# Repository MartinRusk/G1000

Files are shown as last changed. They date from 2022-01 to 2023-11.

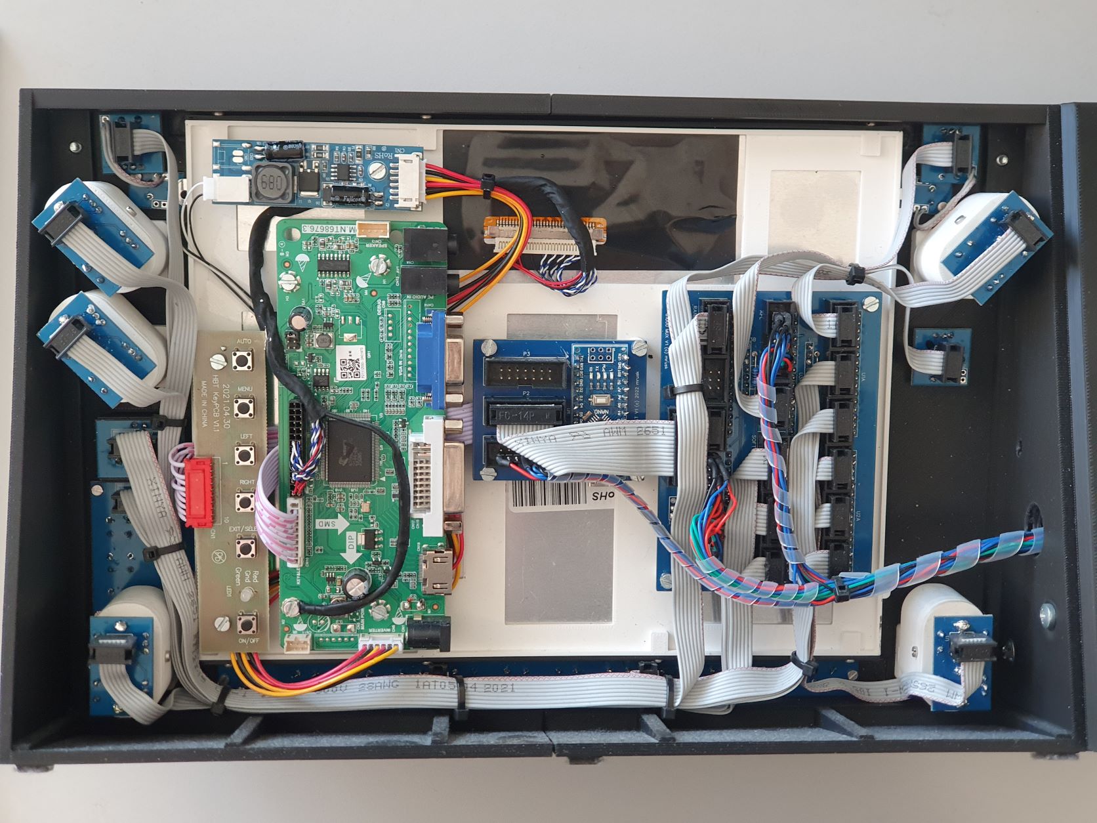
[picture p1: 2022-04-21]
design/G1000 Rear side.jpg

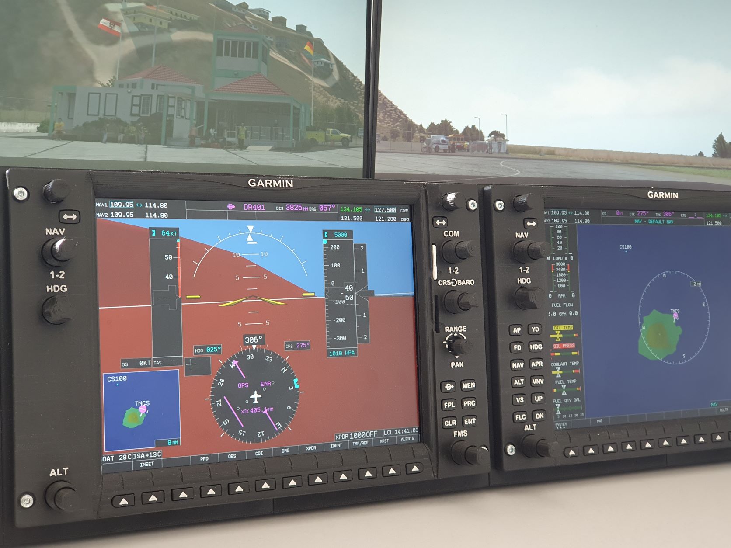
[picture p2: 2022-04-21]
design/G1000.jpg

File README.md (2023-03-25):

# G1000 

This repository hosts the firmware and design files for the mrusk G1000 device. 

The master branch now uses the XPLDirect driver for X-Plane by Curiosity Workshop. Software is (c) by mrusk and Curiosity Workshop. 
For the previously supported RealSimGear driver solution (also for MSFS2020) please look into the RealSimGear branch. Software provided here is licensed under GPL V3.0 License.

Please visit the Curiosity Workshop Discord https://discord.gg/gzXetjEST4 and the FlightSimMaker Discord https://discord.gg/YVbK6dmkeV.

3D Design also available at Printables: https://www.printables.com/de/model/199536-flight-simulator-g1000-nxi

PCBs to build the solution are currently out of stock. Order details are given in the building instructions. In case of trouble you may contact me via g1000nxi@outlook.de

3D design files are (c) by DKF and mrusk, licensed under a
[Creative Commons Attribution-NonCommercial-ShareAlike 4.0 International License][cc-by-nc-sa].

[][cc-by-nc-sa]

[cc-by-nc-sa]: http://creativecommons.org/licenses/by-nc-sa/4.0/
[cc-by-nc-sa-image]: https://licensebuttons.net/l/by-nc-sa/4.0/88x31.png
[cc-by-nc-sa-shield]: https://img.shields.io/badge/License-CC%20BY--NC--SA%204.0-lightgrey.svg

PCB design files are (c) by mrusk, licensed under a
[Creative Commons Attribution-NonCommercial-NoDerivatives 4.0 International License][cc-by-nc-nd].

[][cc-by-nc-nd]

[cc-by-nc-nd]: http://creativecommons.org/licenses/by-nc-nd/4.0/
[cc-by-nc-nd-image]: https://licensebuttons.net/l/by-nc-nd/4.0/88x31.png
[cc-by-nc-nd-shield]: https://img.shields.io/badge/License-CC%20BY--NC--ND%204.0-lightgrey.svg

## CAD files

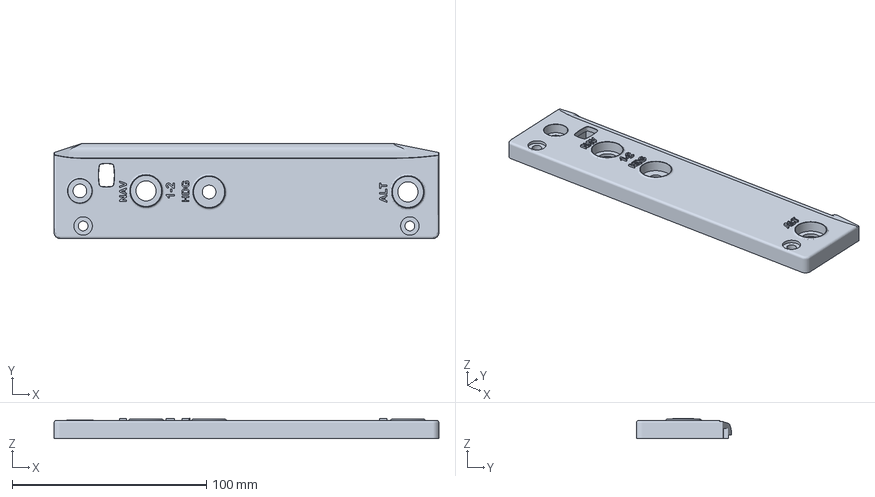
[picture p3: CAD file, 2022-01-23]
design/Bezel/Bezel Left PFD.3mf
198.0 x 49.0 x 10.4 mm

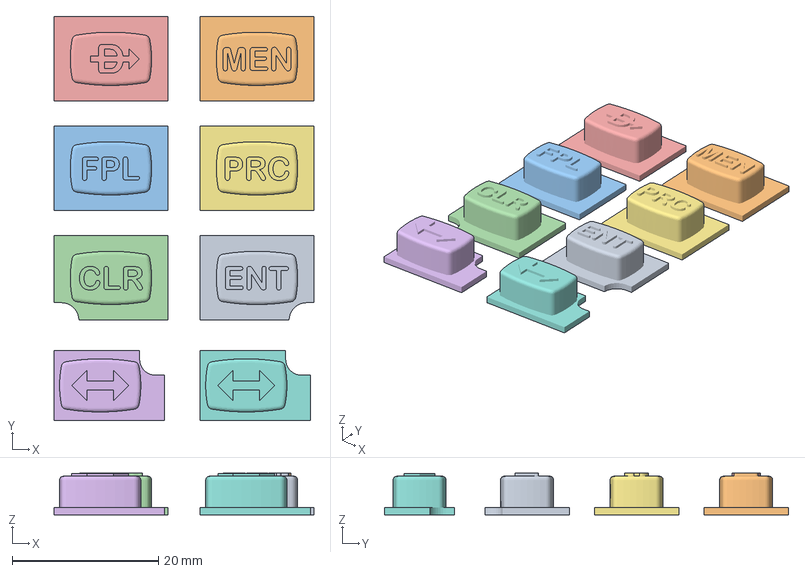
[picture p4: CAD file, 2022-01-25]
design/Buttons/Buttons PFD.3mf
35.6 x 55.3 x 5.69 mm
Buttons erhaben 0.4mm_9
Buttons erhaben 0.4mm_10
Buttons erhaben 0.4mm_12
Buttons erhaben 0.4mm_13
Buttons erhaben 0.4mm_14
Buttons erhaben 0.4mm_17
Buttons erhaben 0.4mm_19
Buttons erhaben 0.4mm_22

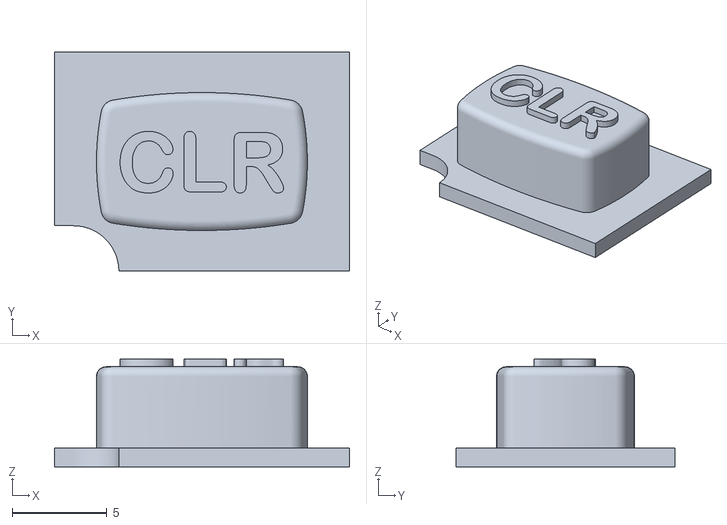
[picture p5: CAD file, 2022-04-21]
design/Buttons/STL/CLR.stl
15.6 x 11.6 x 5.69

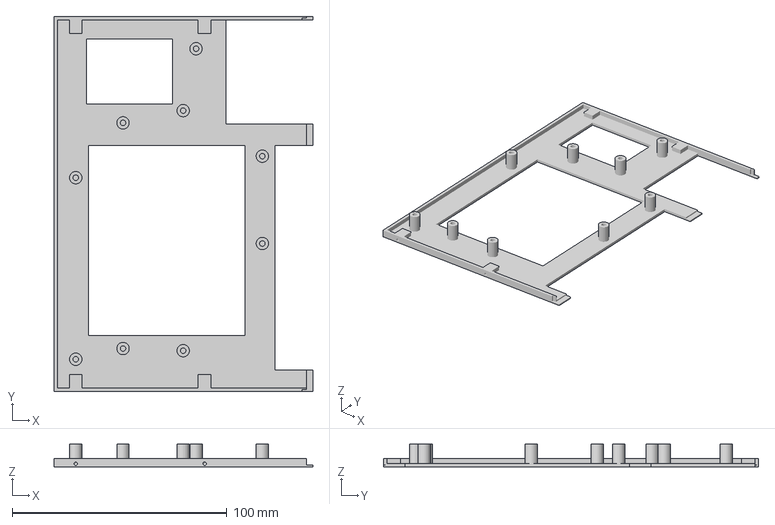
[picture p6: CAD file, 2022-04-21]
design/Display/Display_Bracket_Left.3mf
120.3 x 174.5 x 10.6 mm

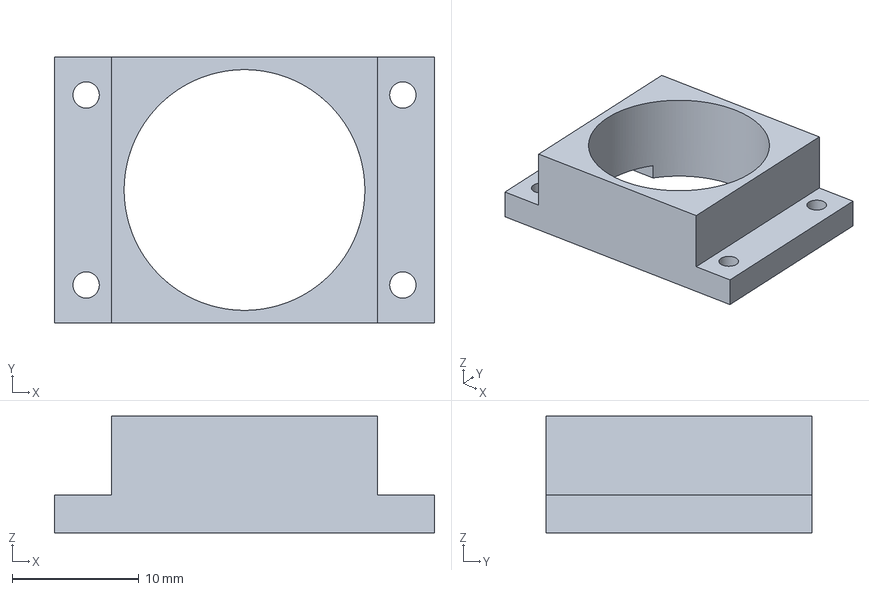
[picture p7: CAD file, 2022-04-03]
design/Encoders/Range Pan Frame.3mf
30.0 x 21.0 x 9.20 mm

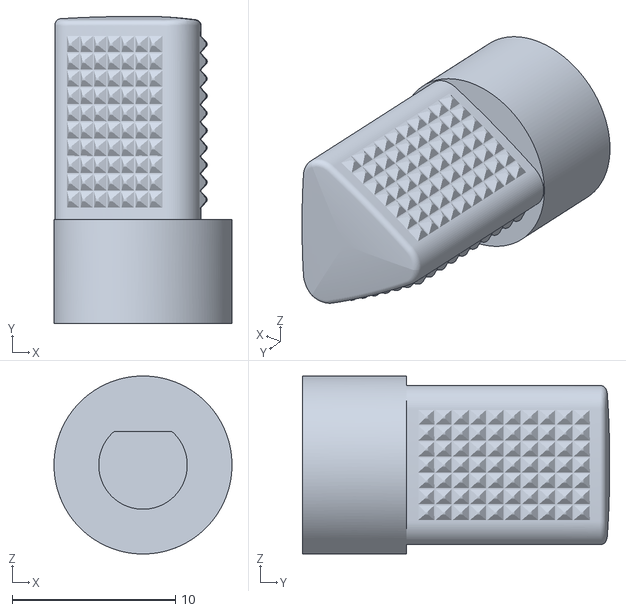
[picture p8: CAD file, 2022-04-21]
design/Encoders/STL/Encoder Knob CRS Inner.stl
10.9 x 18.8 x 10.9

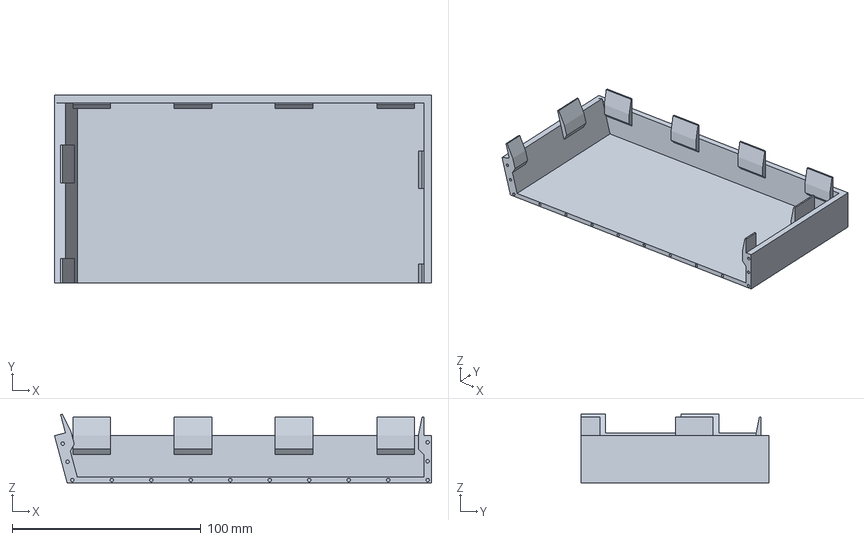
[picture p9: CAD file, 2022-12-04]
design/Housing/Back cover right MFD.3mf
200.0 x 99.5 x 36.5 mm

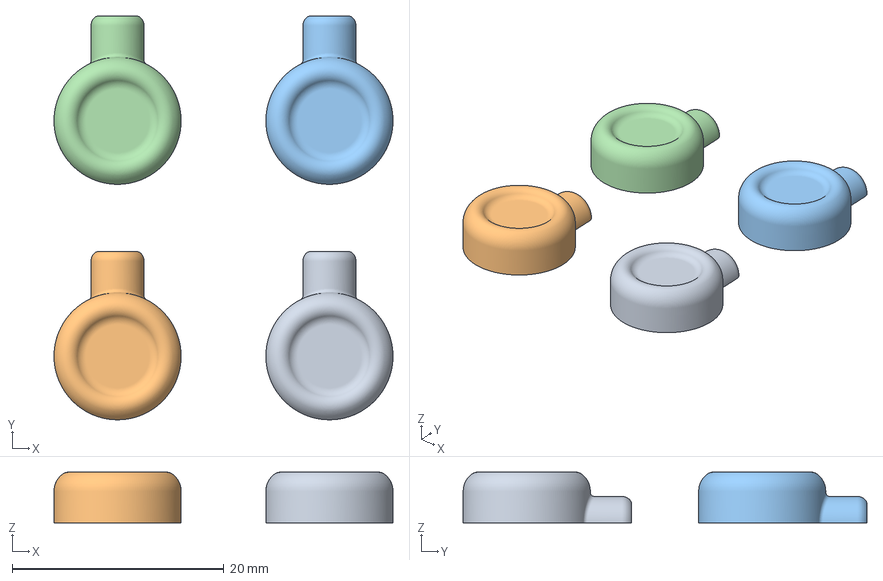
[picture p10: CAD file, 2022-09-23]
design/Panel/Fuel handle.3mf
32.0 x 38.1 x 4.80 mm
Fuel handle right.stl
Fuel handle left.stl

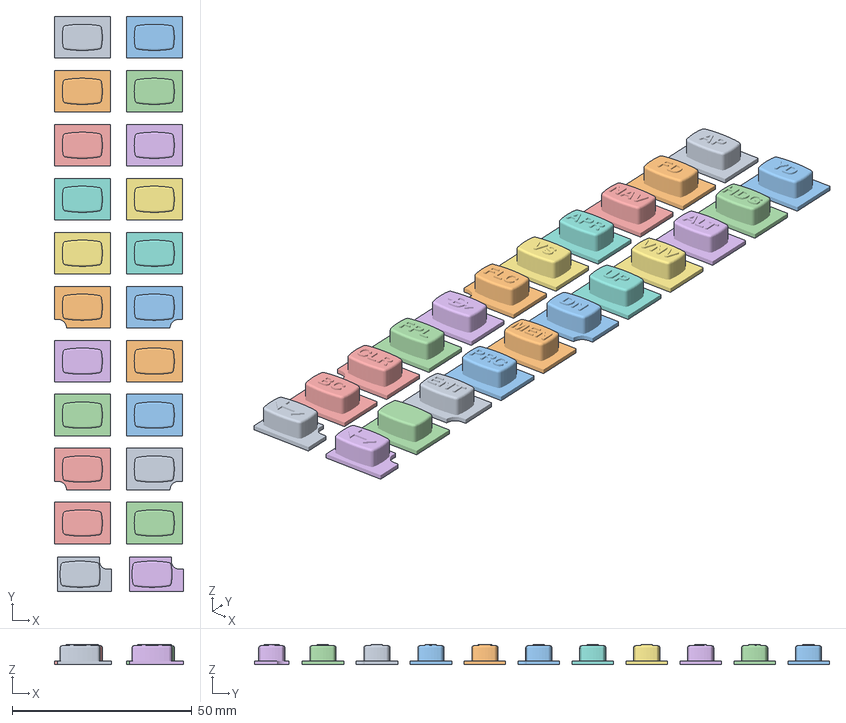
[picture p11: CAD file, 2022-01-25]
design/Buttons/Buttons MFD.3mf
36.0 x 159.8 x 5.69 mm
Buttons erhaben 0.4mm_1
Buttons erhaben 0.4mm_2
Buttons erhaben 0.4mm_3
Buttons erhaben 0.4mm_4
Buttons erhaben 0.4mm_5
Buttons erhaben 0.4mm_6
Buttons erhaben 0.4mm_7
Buttons erhaben 0.4mm_8
Buttons erhaben 0.4mm_9
Buttons erhaben 0.4mm_10
Buttons erhaben 0.4mm_11
Buttons erhaben 0.4mm_12
Buttons erhaben 0.4mm_13
Buttons erhaben 0.4mm_14
Buttons erhaben 0.4mm_15
Buttons erhaben 0.4mm_16
Buttons erhaben 0.4mm_17
Buttons erhaben 0.4mm_18
Buttons erhaben 0.4mm_19
Buttons erhaben 0.4mm_20
Buttons erhaben 0.4mm_21
Buttons erhaben 0.4mm_22

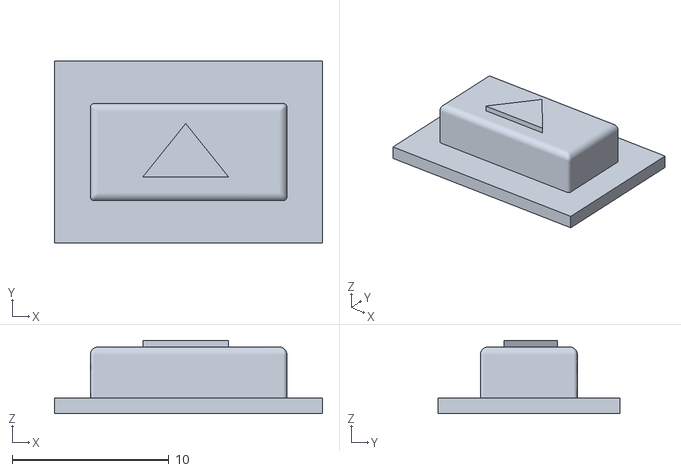
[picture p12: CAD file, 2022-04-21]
design/Buttons/STL/KEY 8.stl
17.1 x 11.6 x 4.67

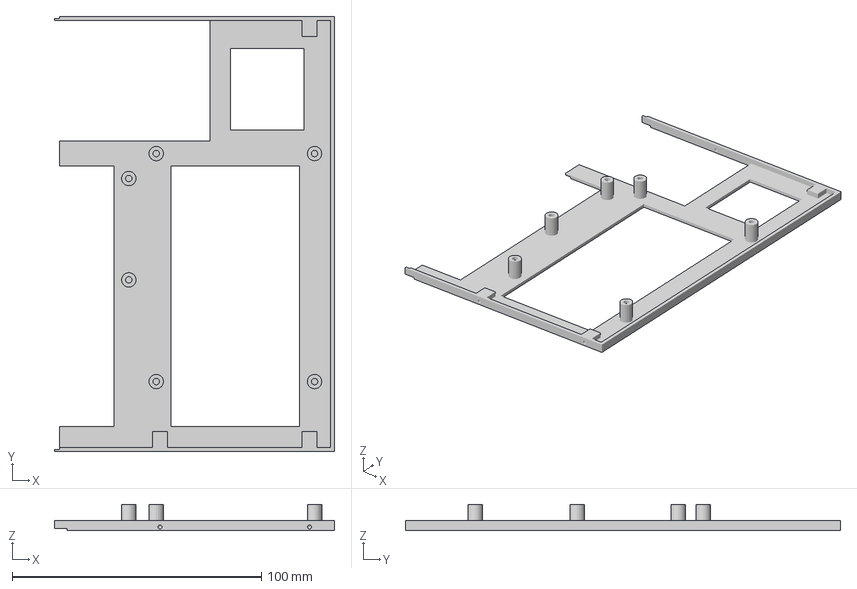
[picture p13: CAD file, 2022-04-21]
design/Display/Display_Bracket_Right.3mf
112.3 x 174.5 x 10.6 mm

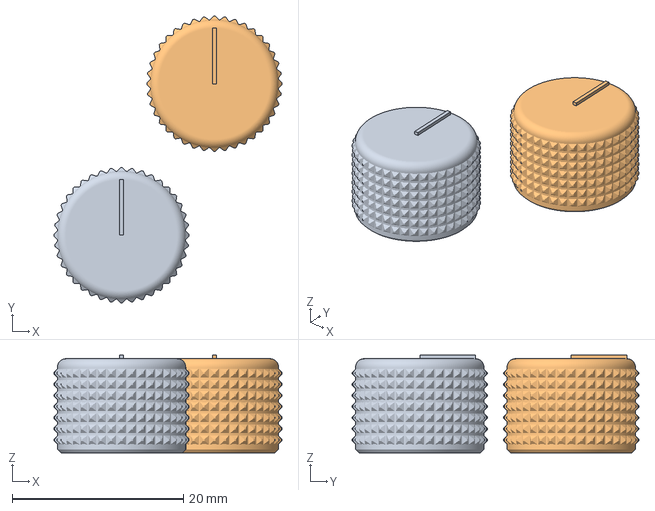
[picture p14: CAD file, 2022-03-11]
design/Encoders/Poti Knob.3mf
26.7 x 33.5 x 11.4 mm

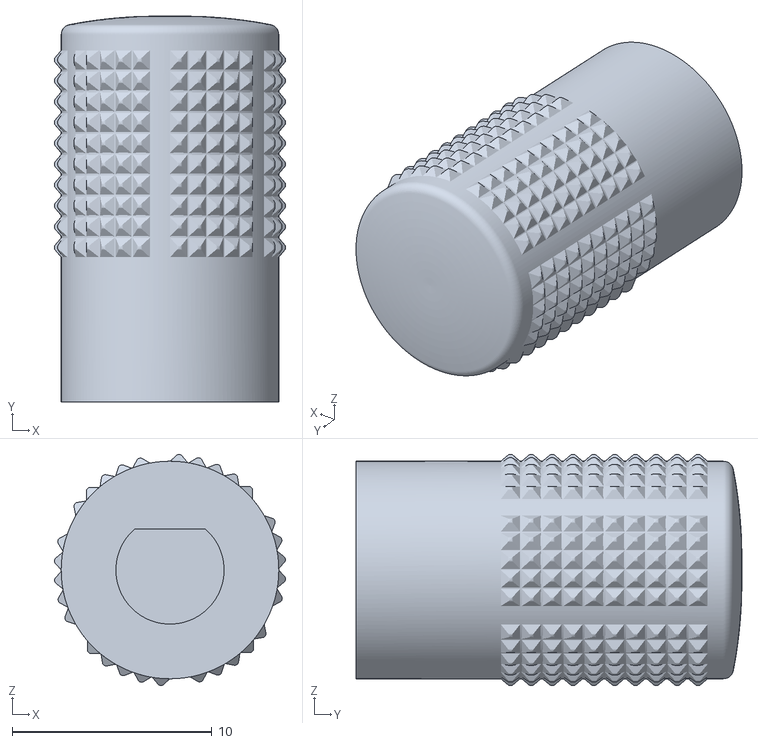
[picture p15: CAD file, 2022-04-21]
design/Encoders/STL/Encoder Knob Dual Inner.stl
11.6 x 19.3 x 11.6

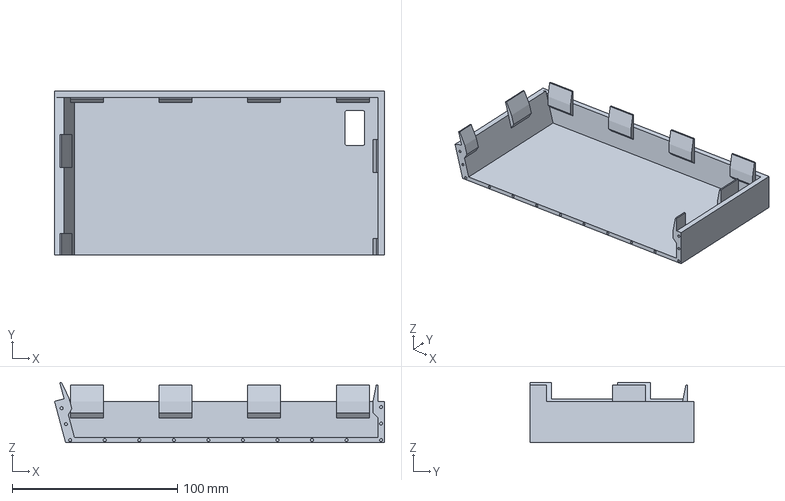
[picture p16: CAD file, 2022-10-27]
design/Housing/Back cover right PFD.3mf
200.0 x 99.5 x 36.5 mm

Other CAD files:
design/Bezel/Bezel Left MFD.3mf
design/Panel/Gear handle.3mf
design/Bezel/Bezel Top.3mf
design/Buttons/Buttons KEY.3mf
design/Bezel/Bezel Bottom.3mf
design/Bezel/Bezel Right.3mf
design/Bezel/Bezel SD Card.3mf
design/Bezel/STL/Bezel Bottom.stl
design/Bezel/STL/Bezel Left MFD.stl
design/Bezel/STL/Bezel Left PFD.stl
design/Bezel/STL/Bezel Right.stl
design/Bezel/STL/Bezel SD Card.stl
design/Bezel/STL/Bezel Top.stl
design/Buttons/STL/ALT.stl
design/Buttons/STL/AP.stl
design/Buttons/STL/APR.stl
design/Buttons/STL/BC.stl
design/Buttons/STL/Blank.stl
design/Buttons/STL/DN.stl
design/Buttons/STL/Dto.stl
design/Buttons/STL/ENT.stl
design/Buttons/STL/FD.stl
design/Buttons/STL/FFL.stl
design/Buttons/STL/FFR.stl
design/Buttons/STL/FLC.stl
design/Buttons/STL/FPL.stl
design/Buttons/STL/HDG.stl
design/Buttons/STL/KEY 1.stl
design/Buttons/STL/KEY 10.stl
design/Buttons/STL/KEY 11.stl
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

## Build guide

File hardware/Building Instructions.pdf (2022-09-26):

# Building the mrusk G1000 panel

## Part list for PFD+MFD

Part | Type | Amount | Source
PCB set | | 1 | mrusk
Encoder | EC11 | 26 | https://www.ebay.de/itm/182373237976
ALPS | RKJXT1F42001 | 2 | https://www.ebay.de/itm/164837499516
Switch | 6x6x5mm | 52 | https://www.reichelt.de/kurzhubtaster-6x6mm-hoehe-5-0mm-12v-vertikal-taster-9302-p44579.html (https://www.reichelt.de/kurzhubtaster-6x6mm-hoehe-5-0mm-12v-vertikal-taster-9302-p44579.html)
IDC Header | 6 pin | 18 | https://www.ebay.de/itm/362257230215
IDC Plug | 6 pin | 34 | https://www.ebay.de/itm/183463370948
IDC Header | 8 pin | 8 | https://www.ebay.de/itm/312078634350
IDC Plug | 8 pin | 16 | https://www.ebay.de/itm/312252897256
IDC Header | 14 pin | 8 | https://www.ebay.de/itm/312078591715
IDC Plug | 14 pin | 9 | https://www.ebay.de/itm/312252873182
Pin Header | Single row | Ca. 300 pins | https://www.reichelt.de/40pol-stiftleiste-gerade-rm-2-54-sl-1x40g-2-54-p19506.html (https://www.reichelt.de/40pol-stiftleiste-gerade-rm-2-54-sl-1x40g-2-54-p19506.html)
Pin Header | Double row | Ca. 70x2 pins | https://www.reichelt.de/2x40pol-stiftleiste-gerade-rm-2-54-sl-2x40g-2-54-p19498.html (https://www.reichelt.de/2x40pol-stiftleiste-gerade-rm-2-54-sl-2x40g-2-54-p19498.html)
Resistor 1/4W | 10 kΩ | 10
74HC4067 | Module | 10 | https://www.ebay.de/itm/265408479238
Screw | M3x5mm | 30
Screw | M2x5mm | 20
Ribbon cable | 14pin (Split for 6 and 8) | | https://www.reichelt.de/flachbandkabel-awg28-14-pol-grau-10m-ring-awg-28-14g-10m-p47653.html (https://www.reichelt.de/flachbandkabel-awg28-14-pol-grau-10m-ring-awg-28-14g-10m-p47653.html)
Display | VS104T-003 | 2 | https://de.aliexpress.com/item/4000156062102.html
Arduino MEGA 2560 | | 1

For OPTIONAL Backlight
LED white 1206 | white | 24 | https://www.reichelt.de/led-smd-3216-1206-warmweiss-900-mcd-120--led-ll-1206-ww-p156359.html (https://www.reichelt.de/led-smd-3216-1206-warmweiss-900-mcd-120--led-ll-1206-ww-p156359.html)
Resistor 1206 | 100 Ω | 24 | https://www.reichelt.de/smd-widerstand-1206-100-ohm-250-mw-1--vis-crcw12061002-p238101.html (https://www.reichelt.de/smd-widerstand-1206-100-ohm-250-mw-1--vis-crcw12061002-p238101.html)

## PCB Set

Shortcut | Usage | Amount | Panel Size | Panels needed
APL | Autopilot (MFD only) | 1 | 2 x 1 | 1
FMS | Flight Management System | 2 | 2 x 1 | 1
Enc | Single Encoder (Volume, Heading) | 6 | 4 x 4 | 1
DualEnc | Dual Encoder | 10 | 2 x 4 | 2
FF | Frequency Flip Flop Key | 4 | 4 x 5 | 1
Range | Range/Pan knob | 2 | 2 x 3 | 1
Softkey | Softkey bar | 2 | 1 x 1 | 2
MUX | Multiplexer carrier | 2 | 1 x 1 | 2
HAT | Connector to Arduino MEGA 2560 | 1 | 1 x 2 | 1
MICRO_HAT and NANO_HAT are for Arduino Pro Micro and Arduino Nano respectively, but are not really recommended due to performance and driver issues.

Order using the Gerber files at https://jlcpcb.com. Set the parameters according to the screenshot below (example is for APL board). Dimensions are determined automatically from the Gerber file. Select “Panel by Customer” and set Columns / Rows according to the table above. PCB Color blue if you like and make sure the “Stencil” at the bottom of the page is not selected. Minimum Quantity is 5 panels each.

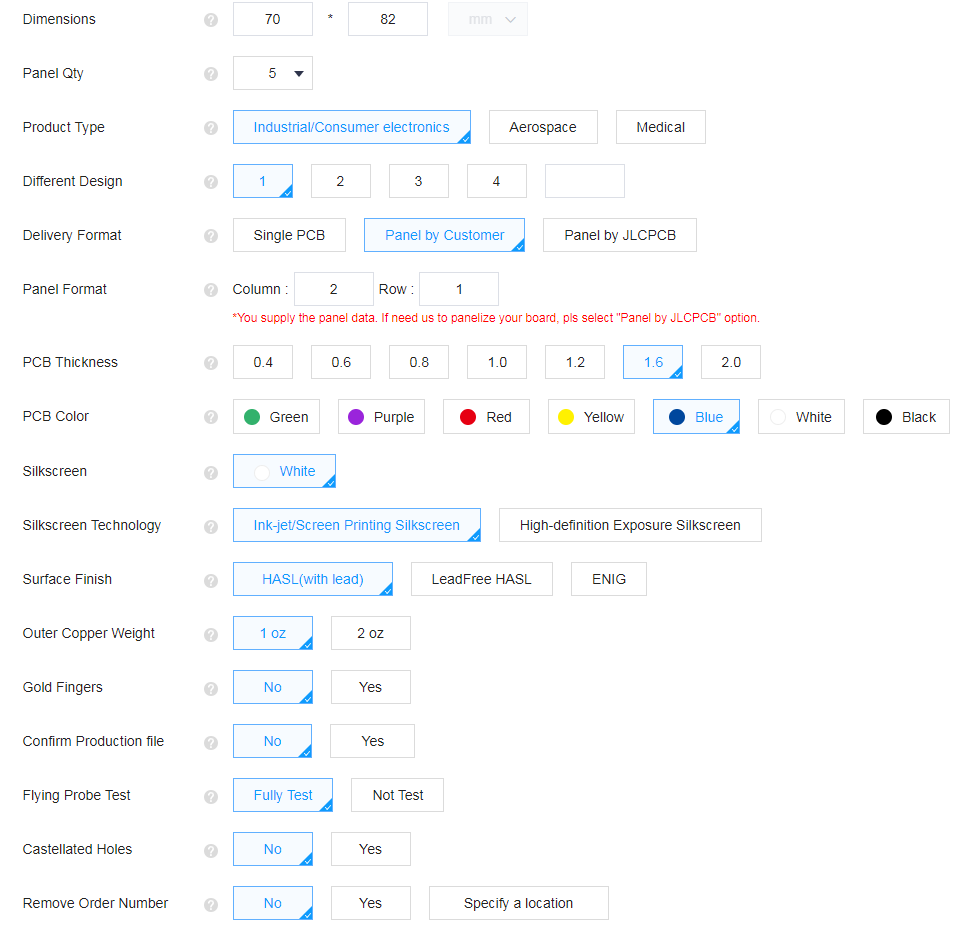
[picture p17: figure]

## Special mounting instructions

MUX Board
- Mount Multiplexers on BOTTOM side, parts facing UPWARDS (see picture). Spacing by headers with additional separator from further header pins.
- MUX 6 is optional and can be left free.
- Solder IDC sockets first and MUX boards last when all pins were tested.
ENC and DENC Boards
- Use 2x3 header pin, not IDC connector. Remove plastic pin underneath the encoder. Space is needed for header pins.
- Each ENC board has one free input (connect to FF boards).
- Connector on DENC board is facing to the outside
RANGE Board
- Solder pin header from bottom so that the pins do not appear on top side. FF Board
- Wire J1 directly to ENC board next to it.
HAT board
- Solder header connection to MEGA2560 on bottom side.
- One 14 pin cable per unit, two slots are spare.

MUX Inputs
DENC1 | NAV
DENC2 | COM
DENC3 | CRS/BARO
DENC4 | ALT
DENC5 | FMS
ENC1 | NAV VOL
ENC2 | COM VOL
ENC3 | HDG
DENC6 | spare

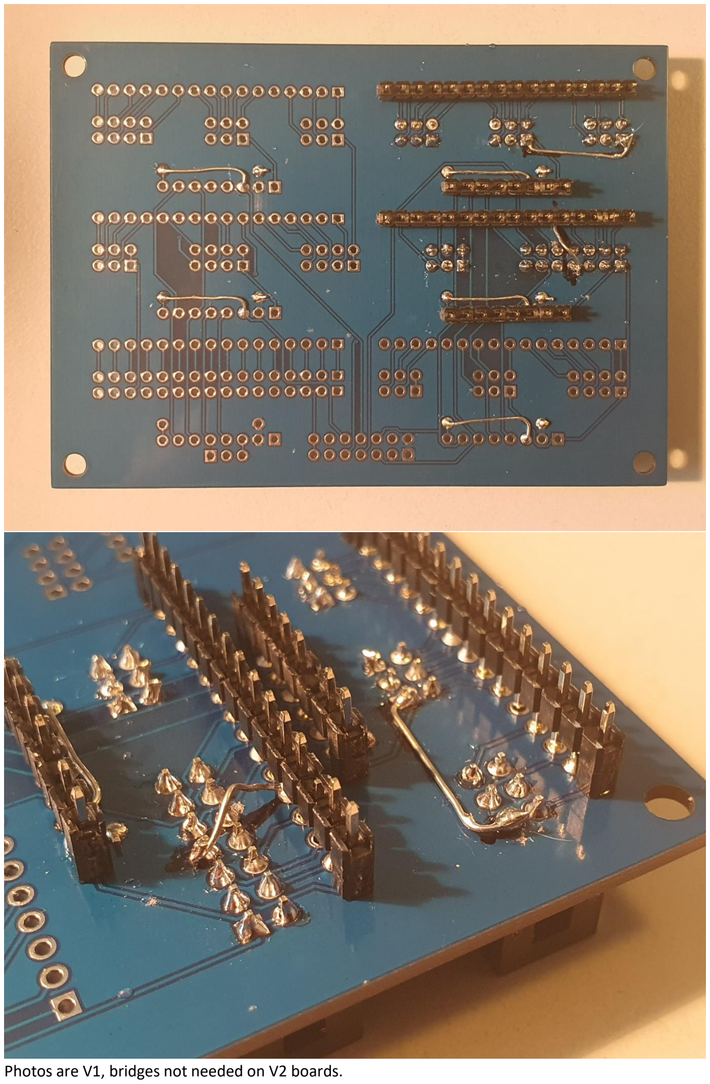
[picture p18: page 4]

Photos are V1, bridges not needed on V2 boards.

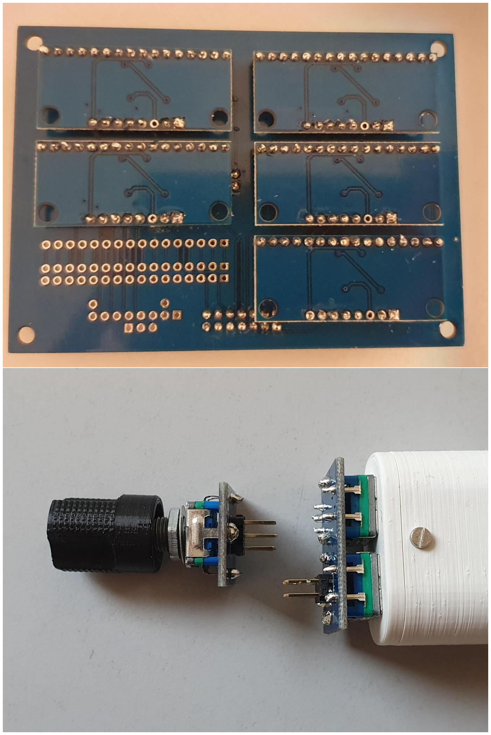
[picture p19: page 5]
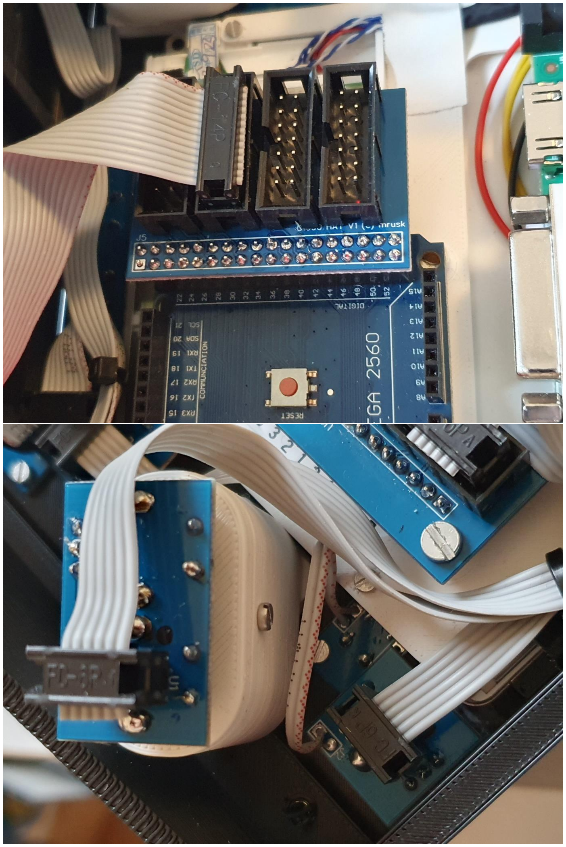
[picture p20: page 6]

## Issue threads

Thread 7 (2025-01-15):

Editing of PCBs

Wibbbs, 2025-01-15:
Hello, I would like to use some of the pieces you have in the the repo here but I would like to make a couple small edits to some of the PCBs you have to accept some different buttons that I have. Any change you could post the easyeda files so they could be edited.

Wibbbs, 2025-01-15:
Spoke with you on discord. Thanks for the helpw

Wibbbs, 2025-01-15:
Spoke with you on discord, thanks for the help.

Closed 2025-01-15.

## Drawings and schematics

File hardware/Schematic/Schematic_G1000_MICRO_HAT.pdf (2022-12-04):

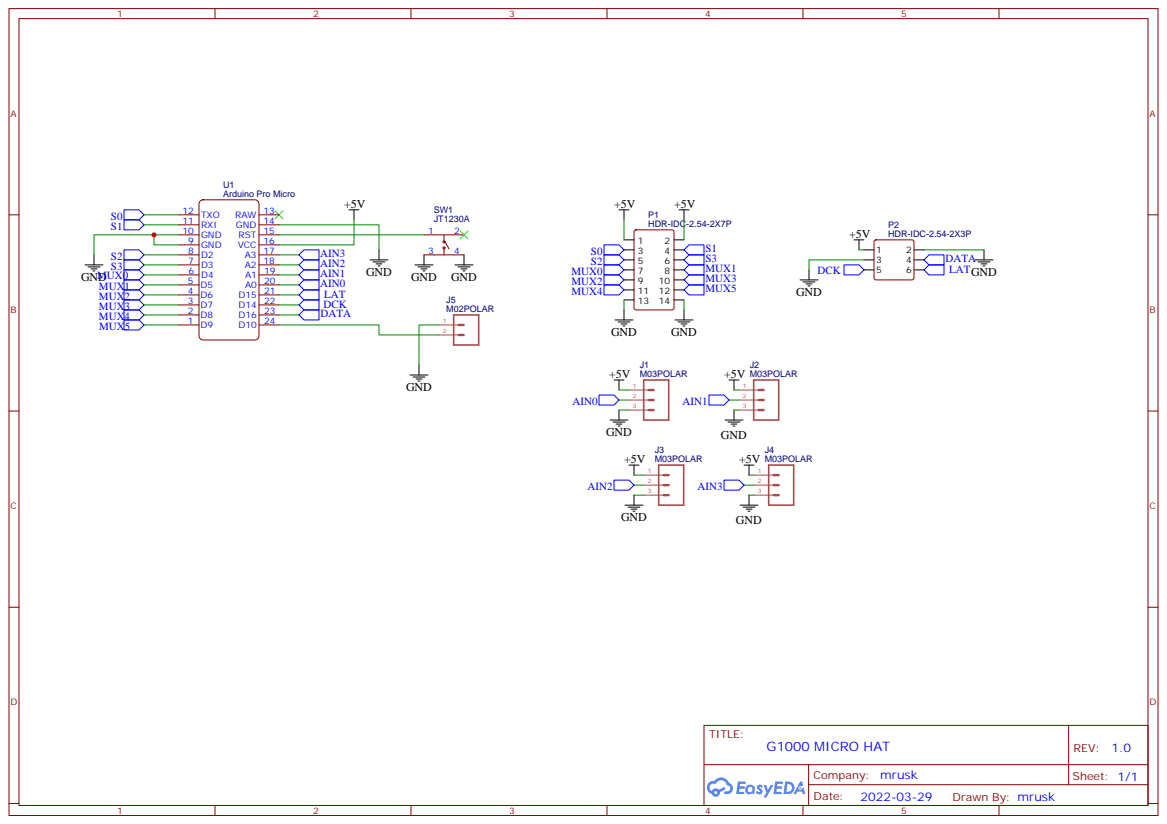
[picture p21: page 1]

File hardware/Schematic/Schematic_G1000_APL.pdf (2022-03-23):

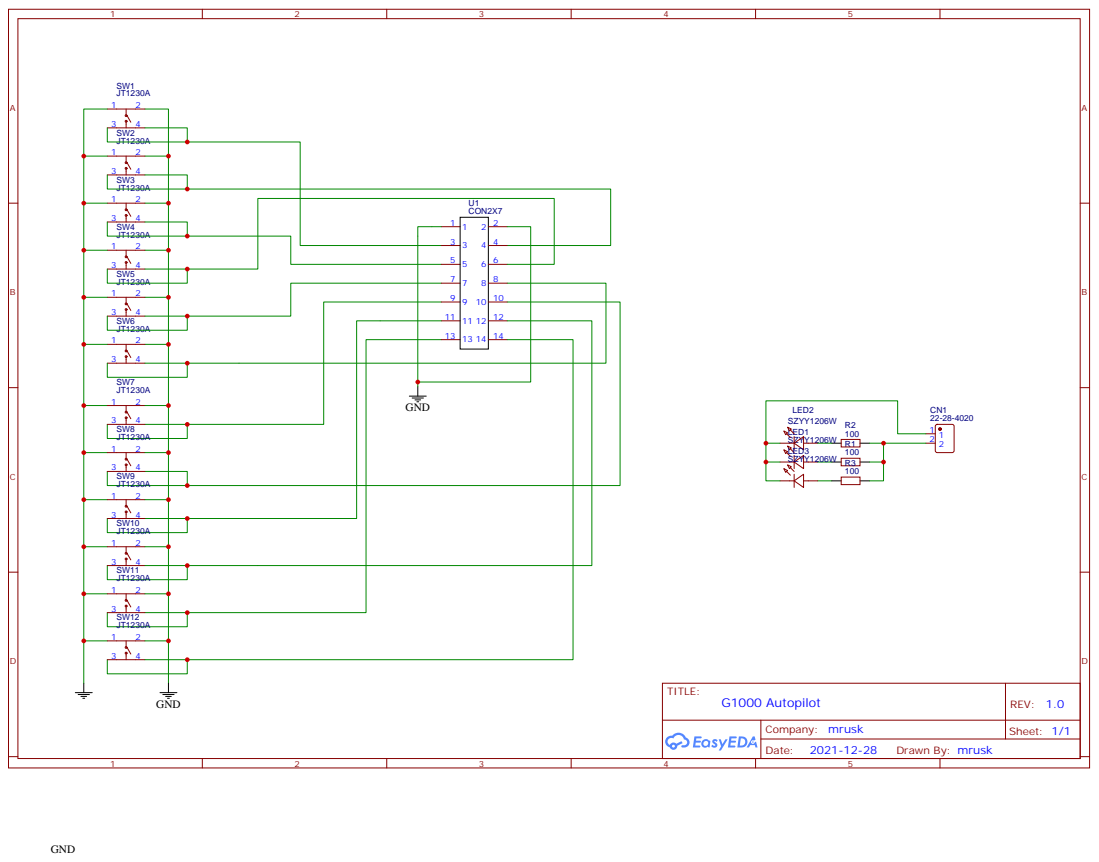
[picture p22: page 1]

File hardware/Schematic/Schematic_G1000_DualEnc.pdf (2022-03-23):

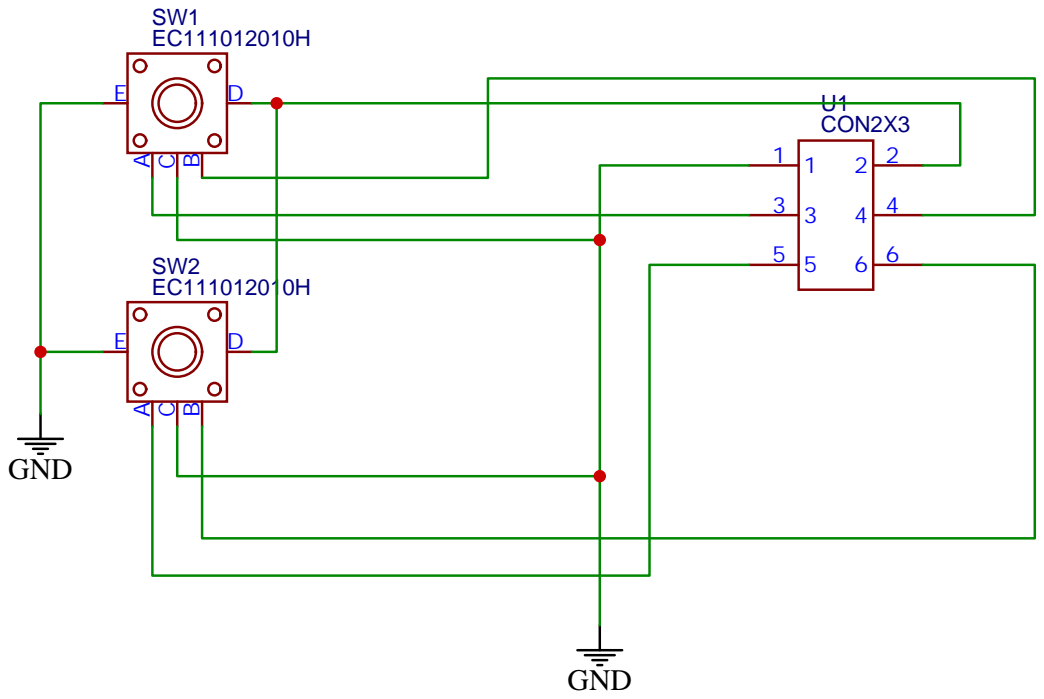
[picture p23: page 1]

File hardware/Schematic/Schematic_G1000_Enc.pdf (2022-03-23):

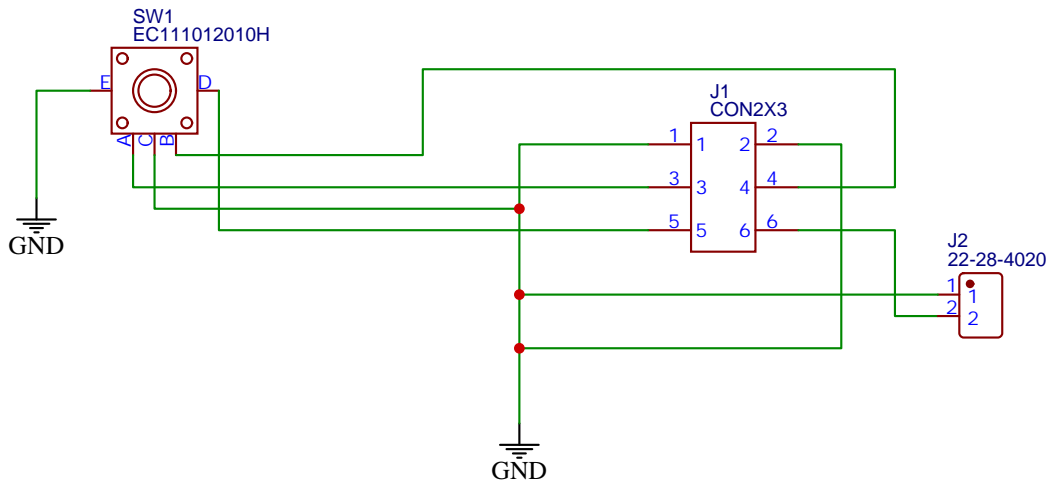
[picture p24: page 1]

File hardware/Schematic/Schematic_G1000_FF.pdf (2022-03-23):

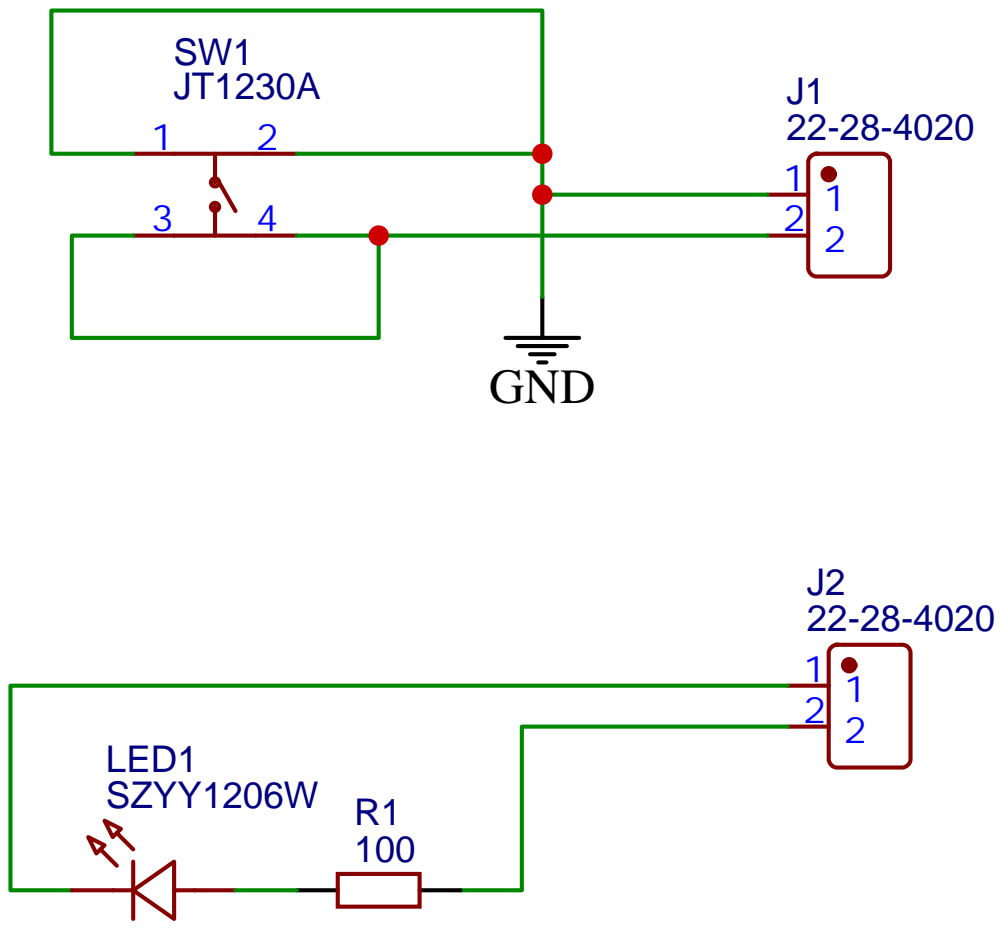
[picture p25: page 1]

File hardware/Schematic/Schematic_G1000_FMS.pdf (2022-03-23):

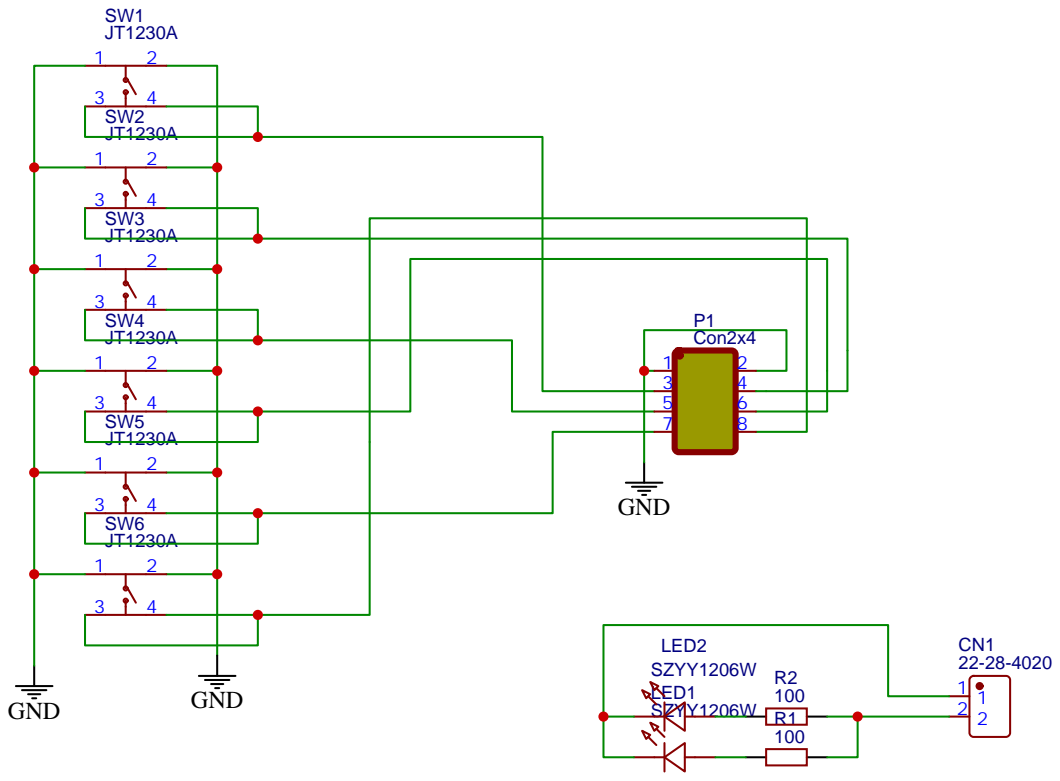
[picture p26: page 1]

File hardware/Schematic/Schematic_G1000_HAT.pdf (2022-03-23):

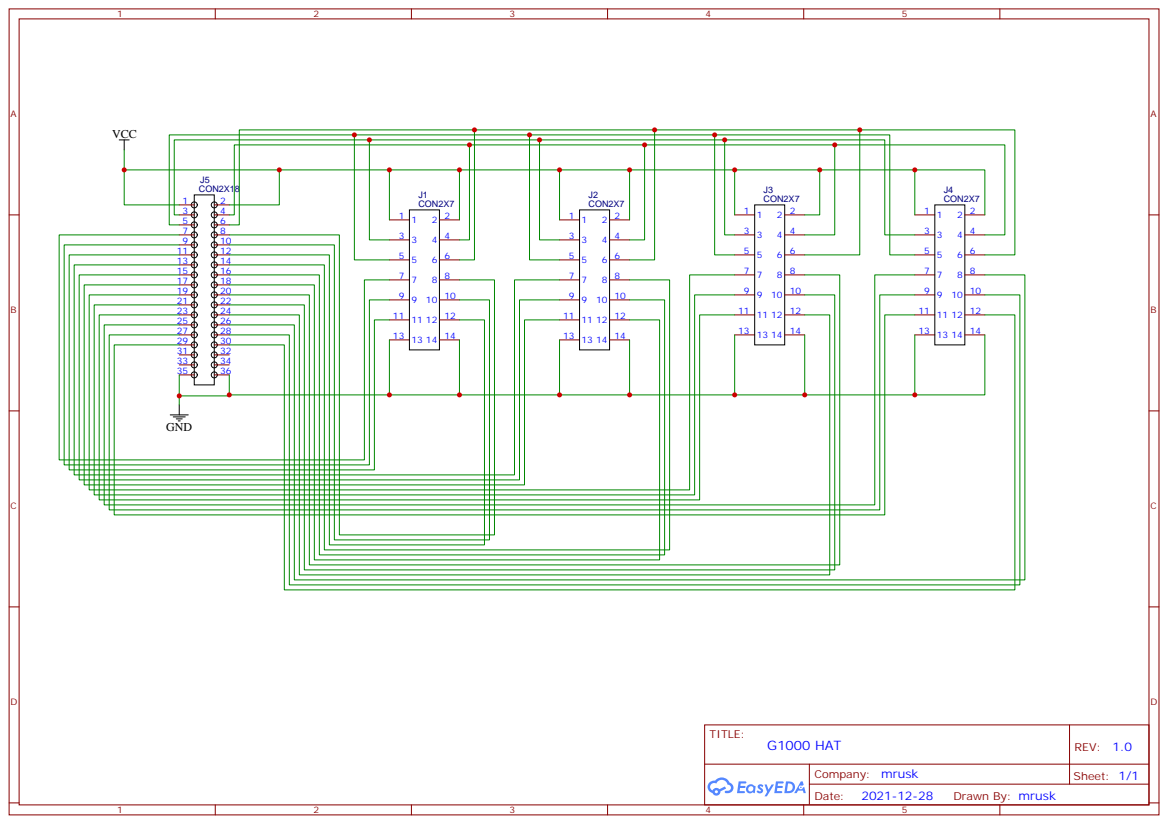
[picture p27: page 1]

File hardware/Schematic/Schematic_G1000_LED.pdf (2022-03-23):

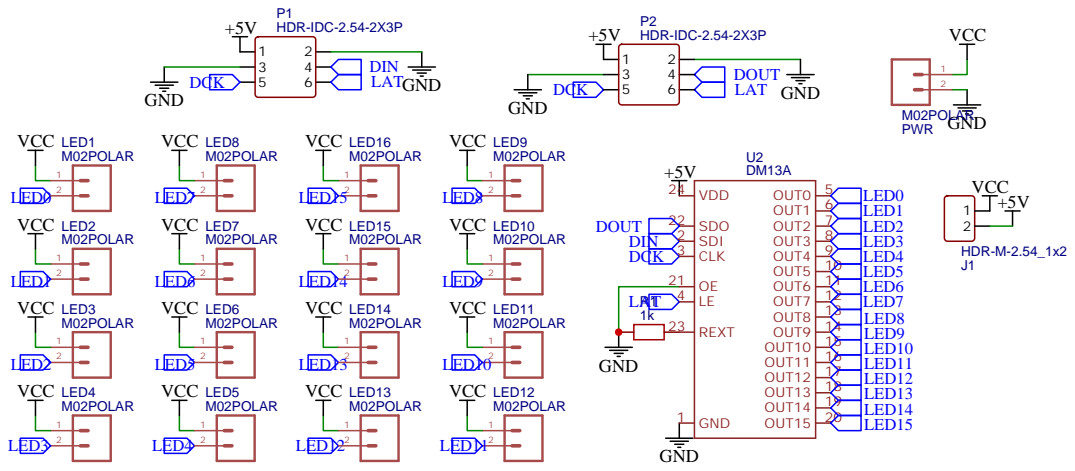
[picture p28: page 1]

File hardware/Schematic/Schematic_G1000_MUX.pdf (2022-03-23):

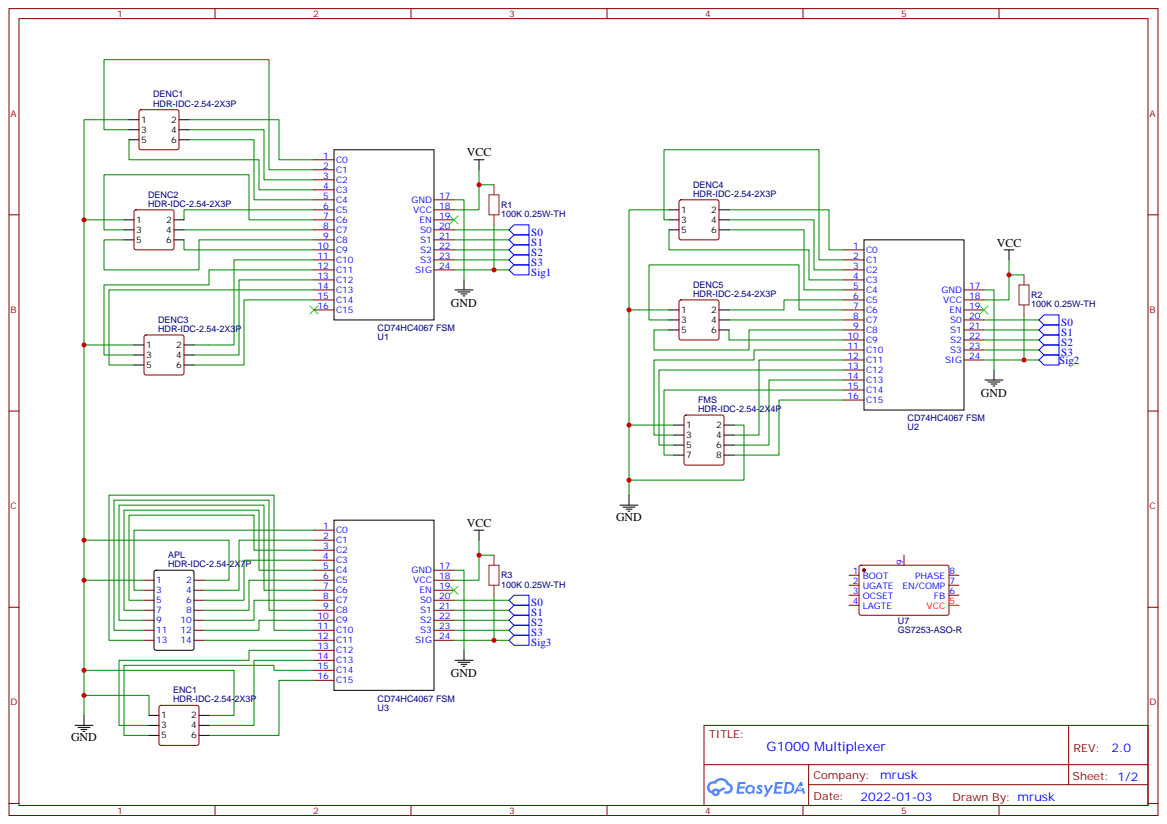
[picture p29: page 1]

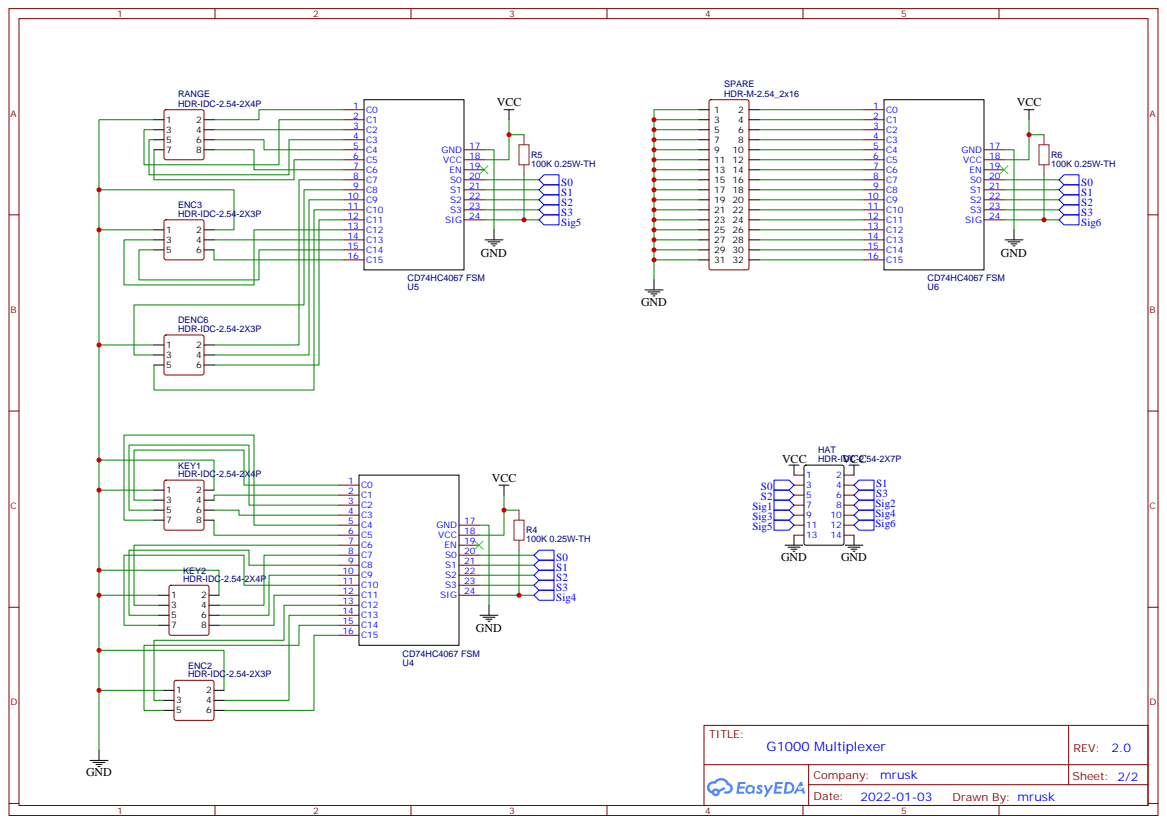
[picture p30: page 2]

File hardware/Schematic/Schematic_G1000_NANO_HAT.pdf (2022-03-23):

A | A

1

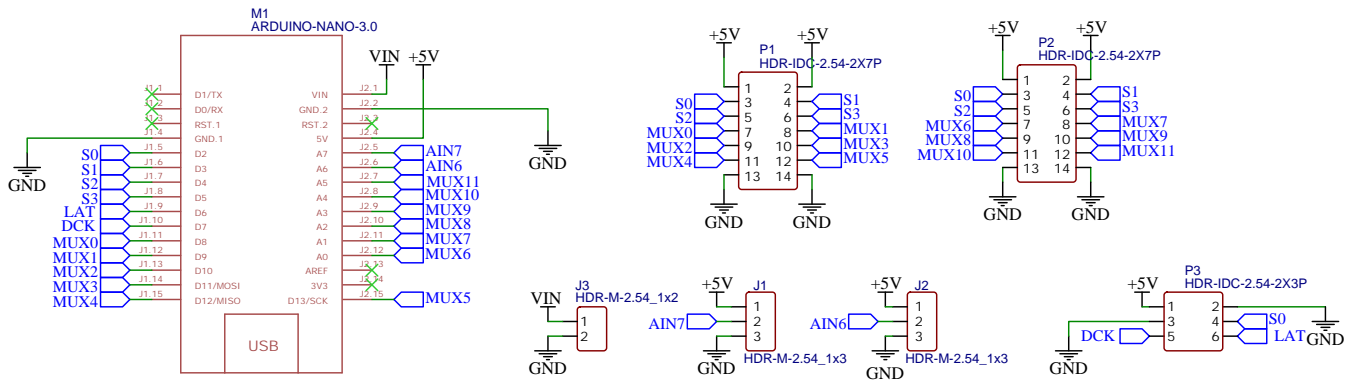
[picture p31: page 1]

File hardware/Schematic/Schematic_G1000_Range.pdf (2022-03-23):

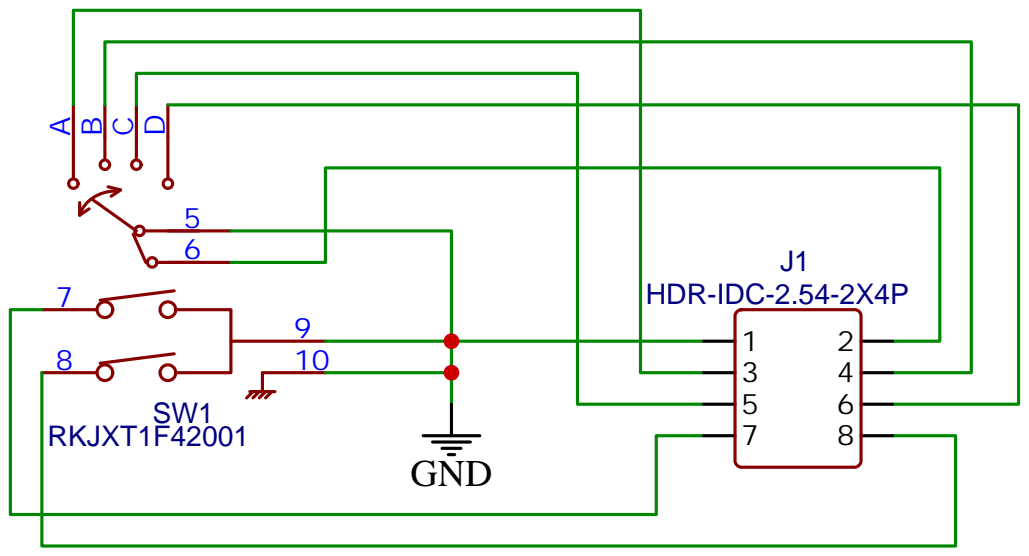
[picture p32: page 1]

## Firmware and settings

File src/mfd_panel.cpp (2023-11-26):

#include <Arduino.h>
#include <XPLDevices.h>

#if G1000_MFD

// MUX 0
Encoder encNavInner(0, 1, 2, 0, enc4Pulse);
Encoder encNavOuter(0, 4, 3, NOT_USED, enc4Pulse);
Encoder encComInner(0, 6, 7, 5, enc4Pulse);
Encoder encComOuter(0, 9, 8, NOT_USED, enc4Pulse);
Encoder encCourse(0, 11, 12, 10, enc4Pulse);
Encoder encBaro(0, 14, 13, NOT_USED, enc4Pulse);
// MUX 1
Encoder encAltInner(1, 1, 2, 0, enc4Pulse);
Encoder encAltOuter(1, 4, 3, NOT_USED, enc4Pulse);
Encoder encFMSInner(1, 6, 7, 5, enc4Pulse);
Encoder encFMSOuter(1, 9, 8, NOT_USED, enc4Pulse);
Button btnDirect(1, 10);
Button btnFPL(1, 11);
Button btnCLR(1, 12);
Button btnMENU(1, 13);
Button btnPROC(1, 14);
Button btnENT(1, 15);
// MUX 2
Button btnAP(2, 0);
Button btnFD(2, 1);
Button btnNAV(2, 2);
Button btnALT(2, 3);
Button btnVS(2, 4);
Button btnFLC(2, 5);
Button btnYD(2, 6);
Button btnHDG(2, 7);
Button btnAPR(2, 8);
Button btnVNAV(2, 9);
Button btnUP(2, 10);
Button btnDN(2, 11);
Encoder encNavVol(2, 12, 13, 14, enc4Pulse);
Button btnNavFF(2, 15);
// MUX3
Button btnSoft1(3, 0);
Button btnSoft2(3, 1);
Button btnSoft3(3, 2);
Button btnSoft4(3, 3);
Button btnSoft5(3, 4);
Button btnSoft6(3, 5);
Button btnSoft7(3, 6);
Button btnSoft8(3, 7);
Button btnSoft9(3, 8);
Button btnSoft10(3, 9);
Button btnSoft11(3, 10);
Button btnSoft12(3, 11);
Encoder encComVol(3, 12, 13, 14, enc4Pulse);
Button btnComFF(3, 15);
// MUX4 Pan/Zoom
Encoder encRange(4, 6, 5, 0, enc2Pulse);
Button btnPanPush(4, 0);
RepeatButton btnPanUp(4, 1, 250);
RepeatButton btnPanLeft(4, 2, 250);
RepeatButton btnPanDown(4, 3, 250);
RepeatButton btnPanRight(4, 4, 250);
Encoder encHeading(4, 12, 13, 14, enc4Pulse);

// MFD specific
Encoder encRudderTrim(4, 8, 9, 10, enc4Pulse);
Switch swLightLanding(5, 0);
Switch swLightTaxi(5, 1);
Switch swLightPosition(5, 2);
Switch swLightStrobe(5, 3);
Switch2 swFuelLeft(5, 4, 5);
Switch2 swFuelRight(5, 6, 7);
Switch swFuelAuxLeft(5, 8);
Switch swFuelAuxRight(5, 9);
Button btnGearTest(5, 10);
Switch swGear(5, 11);
Switch2 swFlaps(5, 12, 13);

// Potentiometers
AnalogIn potInstr(0, unipolar, 10);
AnalogIn potFlood(1, unipolar, 10);

// LEDs
LedShift leds(16, 14, 15);
#define LED_FLAP_UP 0
#define LED_FLAP_TO 1
#define LED_FLAP_LDG 2
#define LED_GEAR_NOSE 3
#define LED_GEAR_LEFT 4
#define LED_GEAR_RIGHT 5
#define LED_GEAR_UNSAFE 6

// Timer for Main loop
Timer tmrMain(1000.0);
Timer tmrSync(1000.0);

// DataRefs MUX 5
float gear_ratio[3];
float flap_ratio;
long gear_unsafe;
float light_instr = 0;
float light_flood = 0;
long gear_handle_down;
float flap_handle_request_ratio;

// Setup
void setup()
{
// Setup XP interface
  Serial.begin(XPLDIRECT_BAUDRATE);
  XP.begin("G1000 MFD");

  // Setup Multiplexers
  DigitalIn.setMux(1, 0, 2, 3);
  DigitalIn.addMux(4); // MUX 0
  DigitalIn.addMux(5); // MUX 1
  DigitalIn.addMux(6); // MUX 2
  DigitalIn.addMux(7); // MUX 3
  DigitalIn.addMux(8); // MUX 4
  DigitalIn.addMux(9); // MUX 5

  // init led sequence
  leds.set_all(ledOff);
  for (int pin = 0; pin < 7; pin++)
  {
    leds.set(pin, ledOn);
    leds.handle();
    delay(100);
  }
  leds.set_all(ledOff);

  encNavInner.setCommand(F("sim/GPS/g1000n3_nav_inner_up"), F("sim/GPS/g1000n3_nav_inner_down"), F("sim/GPS/g1000n3_nav12"));
  encNavOuter.setCommand(F("sim/GPS/g1000n3_nav_outer_up"), F("sim/GPS/g1000n3_nav_outer_down"));
  encComInner.setCommand(F("sim/GPS/g1000n3_com_inner_up"), F("sim/GPS/g1000n3_com_inner_down"), F("sim/GPS/g1000n3_com12"));
  encComOuter.setCommand(F("sim/GPS/g1000n3_com_outer_up"), F("sim/GPS/g1000n3_com_outer_down"));
  encCourse.setCommand(F("sim/GPS/g1000n3_crs_up"), F("sim/GPS/g1000n3_crs_down"), F("sim/GPS/g1000n3_crs_sync"));
  encBaro.setCommand(F("sim/GPS/g1000n3_baro_up"), F("sim/GPS/g1000n3_baro_down"));
  encAltInner.setCommand(F("sim/GPS/g1000n3_alt_inner_up"), F("sim/GPS/g1000n3_alt_inner_down"), F("sim/autopilot/altitude_sync"));
  encAltOuter.setCommand(F("sim/GPS/g1000n3_alt_outer_up"), F("sim/GPS/g1000n3_alt_outer_down"));
  encFMSInner.setCommand(F("sim/GPS/g1000n3_fms_inner_up"), F("sim/GPS/g1000n3_fms_inner_down"), F("sim/GPS/g1000n3_cursor"));
  encFMSOuter.setCommand(F("sim/GPS/g1000n3_fms_outer_up"), F("sim/GPS/g1000n3_fms_outer_down"));
  btnDirect.setCommand(F("sim/GPS/g1000n3_direct"));
  btnFPL.setCommand(F("sim/GPS/g1000n3_fpl"));
  btnCLR.setCommand(F("sim/GPS/g1000n3_clr"));
  btnMENU.setCommand(F("sim/GPS/g1000n3_menu"));
  btnPROC.setCommand(F("sim/GPS/g1000n3_proc"));
  btnENT.setCommand(F("sim/GPS/g1000n3_ent"));
  btnAP.setCommand(F("sim/GPS/g1000n3_ap"));
  btnFD.setCommand(F("sim/GPS/g1000n3_fd"));
  btnNAV.setCommand(F("sim/GPS/g1000n3_nav"));
  btnALT.setCommand(F("sim/GPS/g1000n3_alt"));
  btnVS.setCommand(F("sim/GPS/g1000n3_vs"));
  btnFLC.setCommand(F("sim/GPS/g1000n3_flc"));
  btnYD.setCommand(F("sim/systems/yaw_damper_toggle"));
  btnHDG.setCommand(F("sim/GPS/g1000n3_hdg"));
  btnAPR.setCommand(F("sim/GPS/g1000n3_apr"));
  btnVNAV.setCommand(F("sim/GPS/g1000n3_vnv"));
  btnUP.setCommand(F("sim/GPS/g1000n3_nose_up"));
  btnDN.setCommand(F("sim/GPS/g1000n3_nose_down"));
  encNavVol.setCommand(F("sim/GPS/g1000n3_nvol_up"), F("sim/GPS/g1000n3_nvol_dn"), F("sim/GPS/g1000n3_nvol"));
  btnNavFF.setCommand(F("sim/GPS/g1000n3_nav_ff"));
  btnSoft1.setCommand(F("sim/GPS/g1000n3_softkey1"));
  btnSoft2.setCommand(F("sim/GPS/g1000n3_softkey2"));
  btnSoft3.setCommand(F("sim/GPS/g1000n3_softkey3"));
  btnSoft4.setCommand(F("sim/GPS/g1000n3_softkey4"));
  btnSoft5.setCommand(F("sim/GPS/g1000n3_softkey5"));
  btnSoft6.setCommand(F("sim/GPS/g1000n3_softkey6"));
  btnSoft7.setCommand(F("sim/GPS/g1000n3_softkey7"));
  btnSoft8.setCommand(F("sim/GPS/g1000n3_softkey8"));
  btnSoft9.setCommand(F("sim/GPS/g1000n3_softkey9"));
  btnSoft10.setCommand(F("sim/GPS/g1000n3_softkey10"));
  btnSoft11.setCommand(F("sim/GPS/g1000n3_softkey11"));
  btnSoft12.setCommand(F("sim/GPS/g1000n3_softkey12"));
  encComVol.setCommand(F("sim/GPS/g1000n3_cvol_up"), F("sim/GPS/g1000n3_cvol_dn"), F("sim/audio_panel/monitor_audio_com2"));
  btnComFF.setCommand(F("sim/GPS/g1000n3_com_ff"));
  encRange.setCommand(F("sim/GPS/g1000n3_range_up"), F("sim/GPS/g1000n3_range_down"));
  btnPanPush.setCommand(F("sim/GPS/g1000n3_pan_push"));
  btnPanUp.setCommand(F("sim/GPS/g1000n3_pan_up"));
  btnPanLeft.setCommand(F("sim/GPS/g1000n3_pan_left"));
  btnPanDown.setCommand(F("sim/GPS/g1000n3_pan_down"));
  btnPanRight.setCommand(F("sim/GPS/g1000n3_pan_right"));
  encHeading.setCommand(F("sim/GPS/g1000n3_hdg_up"), F("sim/GPS/g1000n3_hdg_down"), F("sim/GPS/g1000n3_hdg_sync"));
  encRudderTrim.setCommand(F("sim/flight_controls/rudder_trim_right"), F("sim/flight_controls/rudder_trim_left"), F("sim/flight_controls/rudder_trim_center"));
  btnGearTest.setCommand(F("aerobask/gear_test"));
  swLightStrobe.setCommand(F("sim/lights/strobe_lights_on"), F("sim/lights/strobe_lights_off"));
  swLightPosition.setCommand(F("sim/lights/nav_lights_on"), F("sim/lights/nav_lights_off"));
  swLightTaxi.setCommand(F("sim/lights/taxi_lights_on"), F("sim/lights/taxi_lights_off"));
  swLightLanding.setCommand(F("sim/lights/landing_lights_on"), F("sim/lights/landing_lights_off"));
  swFuelAuxLeft.setCommand(F("aerobask/auxfuel/pump1_up"), F("aerobask/auxfuel/pump1_dn"));
  swFuelAuxRight.setCommand(F("aerobask/auxfuel/pump2_up"), F("aerobask/auxfuel/pump2_dn"));
  swFuelLeft.setCommand(F("aerobask/eng/fuel_lever1_dn"), F("aerobask/eng/fuel_lever1_up"));
  swFuelRight.setCommand(F("aerobask/eng/fuel_lever2_dn"), F("aerobask/eng/fuel_lever2_up"));

  XP.registerDataRef(F("sim/flightmodel2/gear/deploy_ratio"), XPL_READ, 100, 0, &gear_ratio[0], 0);
  XP.registerDataRef(F("sim/flightmodel2/gear/deploy_ratio"), XPL_READ, 100, 0, &gear_ratio[1], 1);
  XP.registerDataRef(F("sim/flightmodel2/gear/deploy_ratio"), XPL_READ, 100, 0, &gear_ratio[2], 2);
  XP.registerDataRef(F("sim/cockpit/warnings/annunciators/gear_unsafe"), XPL_READ, 100, 1, &gear_unsafe);
  XP.registerDataRef(F("sim/flightmodel2/controls/flap1_deploy_ratio"), XPL_READ, 100, 0, &flap_ratio);
  XP.registerDataRef(F("sim/cockpit2/switches/instrument_brightness_ratio"), XPL_WRITE, 100, 0, &light_instr, 0);
  XP.registerDataRef(F("aerobask/knob_inst"), XPL_WRITE, 100, 0, &light_instr);
  XP.registerDataRef(F("sim/cockpit2/switches/panel_brightness_ratio"), XPL_WRITE, 100, 0, &light_flood, 0);
  XP.registerDataRef(F("aerobask/knob_flood"), XPL_WRITE, 100, 0, &light_flood);
  XP.registerDataRef(F("sim/cockpit2/controls/gear_handle_down"), XPL_READWRITE, 100, 0, &gear_handle_down);
  XP.registerDataRef(F("sim/cockpit2/controls/flap_handle_request_ratio"), XPL_READWRITE, 100, 0, &flap_handle_request_ratio);
}

// Main loop
void loop()
{
  XP.xloop();
  DigitalIn.handle();
  leds.handle();

  encNavInner.handleXP();
  encNavOuter.handleXP();
  encComInner.handleXP();
  encComOuter.handleXP();
  encCourse.handleXP();
  encBaro.handleXP();
  encAltInner.handleXP();
  encAltOuter.handleXP();
  encFMSInner.handleXP();
  encFMSOuter.handleXP();
  btnDirect.handleXP();
  btnFPL.handleXP();
  btnCLR.handleXP();
  btnMENU.handleXP();
  btnPROC.handleXP();
  btnENT.handleXP();
  btnAP.handleXP();
  btnFD.handleXP();
  btnNAV.handleXP();
  btnALT.handleXP();
  btnVS.handleXP();
  btnFLC.handleXP();
  btnYD.handleXP();
  btnHDG.handleXP();
  btnAPR.handleXP();
  btnVNAV.handleXP();
  btnUP.handleXP();
  btnDN.handleXP();
  encNavVol.handleXP();
  btnNavFF.handleXP();
  btnSoft1.handleXP();
  btnSoft2.handleXP();
  btnSoft3.handleXP();
  btnSoft4.handleXP();
  btnSoft5.handleXP();
  btnSoft6.handleXP();
  btnSoft7.handleXP();
  btnSoft8.handleXP();
  btnSoft9.handleXP();
  btnSoft10.handleXP();
  btnSoft11.handleXP();
  btnSoft12.handleXP();
  encComVol.handleXP();
  btnComFF.handleXP();
  encRange.handleXP();
  encHeading.handleXP();

  // handle pan stick with logical dependecies
  btnPanPush.handleXP(!DigitalIn.getBit(4, 1) && !DigitalIn.getBit(4, 2) && !DigitalIn.getBit(4, 3) && !DigitalIn.getBit(4, 4));
  btnPanUp.handleXP(DigitalIn.getBit(4, 0));
  btnPanLeft.handleXP(DigitalIn.getBit(4, 0));
  btnPanDown.handleXP(DigitalIn.getBit(4, 0));
  btnPanRight.handleXP(DigitalIn.getBit(4, 0));

  encRudderTrim.handleXP();
  btnGearTest.handleXP();

  swLightStrobe.handleXP();
  swLightPosition.handleXP();
  swLightTaxi.handleXP();
  swLightLanding.handleXP();

  swFuelLeft.handleXP();
  swFuelRight.handleXP();
  swFuelAuxLeft.handleXP();
  swFuelAuxRight.handleXP();

  // Sync Switches 
  if (tmrSync.elapsed())
  {
    XP.commandTrigger(swLightStrobe.getCommand());
    XP.commandTrigger(swLightPosition.getCommand());
    XP.commandTrigger(swLightTaxi.getCommand());
    XP.commandTrigger(swLightLanding.getCommand());
    XP.commandTrigger(swFuelAuxLeft.getCommand());
    XP.commandTrigger(swFuelAuxRight.getCommand());
    if (swFuelLeft.on1() || swFuelLeft.on2())
    {
      XP.commandTrigger(swFuelLeft.getCommand(), 2);
    }
    if (swFuelRight.on1() || swFuelRight.on2())
    {
      XP.commandTrigger(swFuelRight.getCommand(), 2);
    }
  }

  swFlaps.handle();
  flap_handle_request_ratio = swFlaps.value(1.0, 0.5, 0.0);
  swGear.handle();
  gear_handle_down = swGear.value(0.0, 1.0);

  potInstr.handle();
  light_instr = 0.01 * round(100.0 * potInstr.value());
  potFlood.handle();
  light_flood = 0.01 * round(100.0 * potFlood.value());

  // Update flap LEDs
  if (flap_ratio < 0.05)
  {
    leds.set(LED_FLAP_UP, ledOn);
    leds.set(LED_FLAP_TO, ledOff);
    leds.set(LED_FLAP_LDG, ledOff);
  }
  else if (flap_ratio < 0.45)
  {
    leds.set(LED_FLAP_UP, ledOn);
    leds.set(LED_FLAP_TO, ledOn);
    leds.set(LED_FLAP_LDG, ledOff);
  }
  else if (flap_ratio < 0.55)
  {
    leds.set(LED_FLAP_UP, ledOff);
    leds.set(LED_FLAP_TO, ledOn);
    leds.set(LED_FLAP_LDG, ledOff);
  }
  else if (flap_ratio < 0.95)
  {
    leds.set(LED_FLAP_UP, ledOff);
    leds.set(LED_FLAP_TO, ledOn);
    leds.set(LED_FLAP_LDG, ledOn);
  }
  else
  {
    leds.set(LED_FLAP_UP, ledOff);
    leds.set(LED_FLAP_TO, ledOff);
    leds.set(LED_FLAP_LDG, ledOn);
  }

  // gear status LEDs (yellow simulated by flashing)
  leds.set(LED_GEAR_NOSE, (gear_ratio[0] > 0.99) ? ledOn : (gear_ratio[0] < 0.01) ? ledOff : ledFast);
  leds.set(LED_GEAR_LEFT, (gear_ratio[1] > 0.99) ? ledOn : (gear_ratio[1] < 0.01) ? ledOff : ledFast);
  leds.set(LED_GEAR_RIGHT, (gear_ratio[2] > 0.99) ? ledOn : (gear_ratio[2] < 0.01) ? ledOff : ledFast);
  
  // gear unsafe LED
  leds.set(LED_GEAR_UNSAFE, (gear_unsafe != 0) ? ledOn : ledOff);

  // if (tmrMain.elapsed())
  // {
  //   char tmp[16];
  //   sprintf(tmp, " %ld Cycles/s", tmrMain.count());
  //   XP.sendDebugMessage(tmp);
  // }
}

#endif

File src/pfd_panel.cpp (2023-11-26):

#include <Arduino.h>
#include <XPLDevices.h>

#if G1000_PFD

// MUX 0
Encoder encNavInner(0, 1, 2, 0, enc4Pulse);
Encoder encNavOuter(0, 4, 3, NOT_USED, enc4Pulse);
Encoder encComInner(0, 6, 7, 5, enc4Pulse);
Encoder encComOuter(0, 9, 8, NOT_USED, enc4Pulse);
Encoder encCourse(0, 11, 12, 10, enc4Pulse);
Encoder encBaro(0, 14, 13, NOT_USED, enc4Pulse);
// MUX 1
Encoder encAltInner(1, 1, 2, 0, enc4Pulse);
Encoder encAltOuter(1, 4, 3, NOT_USED, enc4Pulse);
Encoder encFMSInner(1, 6, 7, 5, enc4Pulse);
Encoder encFMSOuter(1, 9, 8, NOT_USED, enc4Pulse);
Button btnDirect(1, 10);
Button btnFPL(1, 11);
Button btnCLR(1, 12);
Button btnMENU(1, 13);
Button btnPROC(1, 14);
Button btnENT(1, 15);
// MUX 2
Encoder encNavVol(2, 12, 13, 14, enc4Pulse);
Button btnNavFF(2, 15);
// MUX3
Button btnSoft1(3, 0);
Button btnSoft2(3, 1);
Button btnSoft3(3, 2);
Button btnSoft4(3, 3);
Button btnSoft5(3, 4);
Button btnSoft6(3, 5);
Button btnSoft7(3, 6);
Button btnSoft8(3, 7);
Button btnSoft9(3, 8);
Button btnSoft10(3, 9);
Button btnSoft11(3, 10);
Button btnSoft12(3, 11);
Encoder encComVol(3, 12, 13, 14, enc4Pulse);
Button btnComFF(3, 15);
// MUX4 Pan/Zoom
Encoder encRange(4, 6, 5, 0, enc2Pulse);
Button btnPanPush(4, 0);
RepeatButton btnPanUp(4, 1, 250);
RepeatButton btnPanLeft(4, 2, 250);
RepeatButton btnPanDown(4, 3, 250);
RepeatButton btnPanRight(4, 4, 250);
Encoder encHeading(4, 12, 13, 14, enc4Pulse);

// PFD specific
// MUX2
Switch swMaster(2, 0);
Switch swAVMaster(2, 1);
Switch swPitot(2, 2);
Switch swOxygen(2, 3);
Button btnDeiceMax(2, 5);
Switch2 swDeice(2, 6, 7);
Button btnDeiceWS(2, 8);
Switch2 swDeiceAnnun(2, 9, 10);
Switch swBackup(2, 11);
// MUX 5
Switch swAltLeft(5, 0);
Button btnStartLeft(5, 1);
Button btnStartRight(5, 2);
Switch swAltRight(5, 3);
Switch swPumpLeft(5, 4);
Switch swEngineMasterLeft(5, 5);
Switch swEngineMasterRight(5, 6);
Switch swPumpRight(5, 7);
Switch2 swVoteLeft(5, 8, 9);
Button btnECUTestLeft(5, 10);
Button btnECUTestRight(5, 11);
Switch2 swVoteRight(5, 12, 13);

// Datarefs
float deice_norm;
float deice_high;
float deice_max;

// LEDs
LedShift leds(16, 14, 15);
#define LED_DEICE_MAX 0
#define LED_DEICE_HIGH 1
#define LED_DEICE_NORM 2

// Timer for Main loop
Timer tmrMain(1000.0);
Timer tmrSync(1000.0);

// Setup
void setup()
{
  // Setup XP interface
  Serial.begin(XPLDIRECT_BAUDRATE);
  XP.begin("G1000 PFD");

  // Setup Multiplexers
  DigitalIn.setMux(1, 0, 2, 3);
  DigitalIn.addMux(4); // MUX 0
  DigitalIn.addMux(5); // MUX 1
  DigitalIn.addMux(6); // MUX 2
  DigitalIn.addMux(7); // MUX 3
  DigitalIn.addMux(8); // MUX 4
  DigitalIn.addMux(9); // MUX 5

  // init led sequence
  leds.set_all(ledOff);
  for (int pin = 0; pin < 3; pin++)
  {
    leds.set(pin, ledOn);
    leds.handle();
    delay(100);
  }
  leds.set_all(ledOff);

  encNavInner.setCommand(F("sim/GPS/g1000n1_nav_inner_up"), F("sim/GPS/g1000n1_nav_inner_down"), F("sim/GPS/g1000n1_nav12"));
  encNavOuter.setCommand(F("sim/GPS/g1000n1_nav_outer_up"), F("sim/GPS/g1000n1_nav_outer_down"));
  encComInner.setCommand(F("sim/GPS/g1000n1_com_inner_up"), F("sim/GPS/g1000n1_com_inner_down"), F("sim/GPS/g1000n1_com12"));
  encComOuter.setCommand(F("sim/GPS/g1000n1_com_outer_up"), F("sim/GPS/g1000n1_com_outer_down"));
  encCourse.setCommand(F("sim/GPS/g1000n1_crs_up"), F("sim/GPS/g1000n1_crs_down"), F("sim/GPS/g1000n1_crs_sync"));
  encBaro.setCommand(F("sim/GPS/g1000n1_baro_up"), F("sim/GPS/g1000n1_baro_down"));
  encAltInner.setCommand(F("sim/GPS/g1000n1_alt_inner_up"), F("sim/GPS/g1000n1_alt_inner_down"), F("sim/autopilot/altitude_sync"));
  encAltOuter.setCommand(F("sim/GPS/g1000n1_alt_outer_up"), F("sim/GPS/g1000n1_alt_outer_down"));
  encFMSInner.setCommand(F("sim/GPS/g1000n1_fms_inner_up"), F("sim/GPS/g1000n1_fms_inner_down"), F("sim/GPS/g1000n1_cursor"));
  encFMSOuter.setCommand(F("sim/GPS/g1000n1_fms_outer_up"), F("sim/GPS/g1000n1_fms_outer_down"));
  btnDirect.setCommand(F("sim/GPS/g1000n1_direct"));
  btnFPL.setCommand(F("sim/GPS/g1000n1_fpl"));
  btnCLR.setCommand(F("sim/GPS/g1000n1_clr"));
  btnMENU.setCommand(F("sim/GPS/g1000n1_menu"));
  btnPROC.setCommand(F("sim/GPS/g1000n1_proc"));
  btnENT.setCommand(F("sim/GPS/g1000n1_ent"));
  encNavVol.setCommand(F("sim/GPS/g1000n1_nvol_up"), F("sim/GPS/g1000n1_nvol_dn"), F("sim/GPS/g1000n1_nvol"));
  btnNavFF.setCommand(F("sim/GPS/g1000n1_nav_ff"));
  btnSoft1.setCommand(F("sim/GPS/g1000n1_softkey1"));
  btnSoft2.setCommand(F("sim/GPS/g1000n1_softkey2"));
  btnSoft3.setCommand(F("sim/GPS/g1000n1_softkey3"));
  btnSoft4.setCommand(F("sim/GPS/g1000n1_softkey4"));
  btnSoft5.setCommand(F("sim/GPS/g1000n1_softkey5"));
  btnSoft6.setCommand(F("sim/GPS/g1000n1_softkey6"));
  btnSoft7.setCommand(F("sim/GPS/g1000n1_softkey7"));
  btnSoft8.setCommand(F("sim/GPS/g1000n1_softkey8"));
  btnSoft9.setCommand(F("sim/GPS/g1000n1_softkey9"));
  btnSoft10.setCommand(F("sim/GPS/g1000n1_softkey10"));
  btnSoft11.setCommand(F("sim/GPS/g1000n1_softkey11"));
  btnSoft12.setCommand(F("sim/GPS/g1000n1_softkey12"));
  encComVol.setCommand(F("sim/GPS/g1000n1_cvol_up"), F("sim/GPS/g1000n1_cvol_dn"), F("sim/audio_panel/monitor_audio_com2"));
  btnComFF.setCommand(F("sim/GPS/g1000n1_com_ff"));
  encRange.setCommand(F("sim/GPS/g1000n1_range_up"), F("sim/GPS/g1000n1_range_down"));
  btnPanPush.setCommand(F("sim/GPS/g1000n1_pan_push"));
  btnPanUp.setCommand(F("sim/GPS/g1000n1_pan_up"));
  btnPanLeft.setCommand(F("sim/GPS/g1000n1_pan_left"));
  btnPanDown.setCommand(F("sim/GPS/g1000n1_pan_down"));
  btnPanRight.setCommand(F("sim/GPS/g1000n1_pan_right"));
  encHeading.setCommand(F("sim/GPS/g1000n1_hdg_up"), F("sim/GPS/g1000n1_hdg_down"), F("sim/GPS/g1000n1_hdg_sync"));
  swMaster.setCommand(F("sim/electrical/battery_1_on"), F("sim/electrical/battery_1_off"));
  swAVMaster.setCommand(F("sim/systems/avionics_on"), F("sim/systems/avionics_off"));
  swPitot.setCommand(F("sim/ice/pitot_heat0_on"), F("sim/ice/pitot_heat0_off"));
  swOxygen.setCommand(F("aerobask/oxygen_open"), F("aerobask/oxygen_close"));
  btnDeiceMax.setCommand(F("aerobask/deice/max"));
  swDeice.setCommand(F("aerobask/deice/main_up"), F("aerobask/deice/main_dn"));
  btnDeiceWS.setCommand(F("aerobask/deice/wshld"));
  swDeiceAnnun.setCommand(F("aerobask/deice/annun_up"), F("aerobask/deice/annun_dn"));
  // swBackup.setCommand(();
  swAltLeft.setCommand(F("sim/electrical/generator_1_on"), F("sim/electrical/generator_1_off"));
  btnStartLeft.setCommand(F("sim/starters/engage_starter_1"));
  btnStartRight.setCommand(F("sim/starters/engage_starter_2"));
  swAltRight.setCommand(F("sim/electrical/generator_2_on"), F("sim/electrical/generator_2_off"));
  swPumpLeft.setCommand(F("aerobask/eng/fuel_pump1_on"), F("aerobask/eng/fuel_pump1_off"));
  swEngineMasterLeft.setCommand(F("aerobask/eng/master1_up"), F("aerobask/eng/master1_dn"));
  swEngineMasterRight.setCommand(F("aerobask/eng/master2_up"), F("aerobask/eng/master2_dn"));
  swPumpRight.setCommand(F("aerobask/eng/fuel_pump2_on"), F("aerobask/eng/fuel_pump2_off"));
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

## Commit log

2022-01-23 Added 3D files
    [Bezel Bottom.3mf, Bezel Left MFD.3mf, Bezel Right.3mf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]
2022-01-23 missing files
    [Bezel Left PFD.3mf, Encoder Lids.3mf]
2022-01-25 Updated buttons and display frame
    [Buttons FMS+APL.3mf, Buttons MFD.3mf, Buttons PFD.3mf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]
2022-01-28 Screws moved due to collision with connectors
    [Display Bracket VS104T.3mf, Display Frame VS104T.3mf]
2022-01-28 Added Housing
    [Housing Front.3mf]
2022-01-31 Nano board adaption (class changed to struct)
2022-02-04 Code revised and LED outputs integrated
2022-02-09 Added side panel design
    [Housing Panel.3mf, Panel Left.3mf, Panel Right.3mf]
2022-02-10 Removed arduino.json
2022-02-10 V1.3.6: improved Pan knob design and logic
    [Encoder Knobs.3mf]
2022-02-11 Made pan knob a litte bit longer
    [Encoder Knobs.3mf]
2022-02-11 V1.3.7: fixed issue with encoder overflow
2022-02-11 fixed vote switch definition
2022-02-15 V1.3.8: enhanced debouncing for buttons and switches
2022-02-17 Adaption of LED pins on unit 1 (PFD)
2022-03-11 Added some design files
    [Backcover Panel.3mf, Flap handle.3mf, Gear handle.3mf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]
2022-03-13 V1.4.1: small code cleanup, LEDs on startup
2022-03-14 Added buttons for MFD on connector 2 of HAT-board
2022-03-14 Added commands for MFD on second port of HAT-board in CommandMapping.ini
2022-03-14 V1.5.0: merged extension for two devices
2022-03-22 Added PCB files and Licenses
2022-03-23 Changed Range PCB back to V1 routing
2022-03-23 Added Schematics
2022-04-03 Enlarged PCBs for production
2022-04-03 Adaption for board V2
    [Range Pan Frame.3mf]
2022-04-21 Added STL files
    [ALT.stl, AP.stl, APR.stl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]
2022-04-21 Added split display bracket
    [Display_Bracket_Left.3mf, Display_Bracket_Right.3mf]
2022-04-27 V1.6.0: Pro Micro added as new board type
2022-05-12 Added building instructions for V2 boards
2022-05-12 V3.1.0: Update for RSG V2 driver.
2022-09-22 Added PCB panel size
2022-09-23 Added fuel handle
    [Fuel handle.3mf]
2022-09-23 Added needed PCB panels
2022-09-26 Added oder details for PCBs
2022-09-26 Update README.md
    PCBs out of stock.
2022-09-26 Cleanup for standard board type
2022-09-27 Fixed panel size for FF board
2022-10-11 Added display bracket f3d design for customizing
    [Display Bracket VS104T.f3d]
2022-10-27 Design for back cover added
    [Back cover center.3mf, Back cover center.stl, Back cover left MFD.3mf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]
2022-12-04 Added missing design and schematic, default config
    [Back cover right MFD.3mf]
2023-03-03 initial working Mux and Button lib
2023-03-06 migrated switches to command handling
2023-03-07 renamed timer, simplified MCP handling
2023-03-07 additional command for Switch2
2023-03-14 adaption to modified Switch2 class
2023-03-15 added panel switches for pfd
2023-03-15 wrong data type for deice led datarefs
    [pfd_panel.cpp]
2023-03-18 changed voter switches to new Switch2

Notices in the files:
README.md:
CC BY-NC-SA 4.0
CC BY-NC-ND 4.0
